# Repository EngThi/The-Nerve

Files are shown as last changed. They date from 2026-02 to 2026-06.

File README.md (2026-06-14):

# The Nerve Automation Motherboard

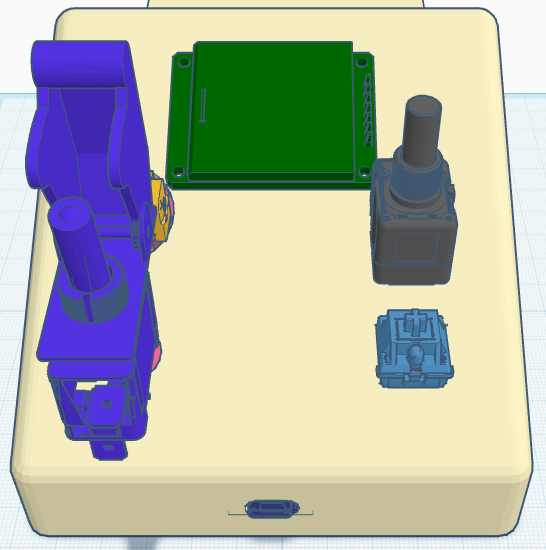
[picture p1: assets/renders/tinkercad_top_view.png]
The Nerve Hero Render


> [!IMPORTANT]
> Reviewer, this project is a custom board placed in Tier 3. To stay within the $100 budget including international shipping fees and taxes, Version A (Round TFT) is the primary build configuration. All components are hand-soldered.



The Nerve is a modular controller for automation workflows and video pipelines. It uses an ESP32-S3 for native Wi-Fi, Bluetooth, and USB HID support.

[Specs](#hardware) | [Logs](JOURNAL.md) | [Budget](BLUEPRINT_BUDGET.md) | [Production](hardware/production/)

---

## Hardware Design

The PCB was designed in EasyEDA and the enclosure in OnShape.

### Enclosure Design
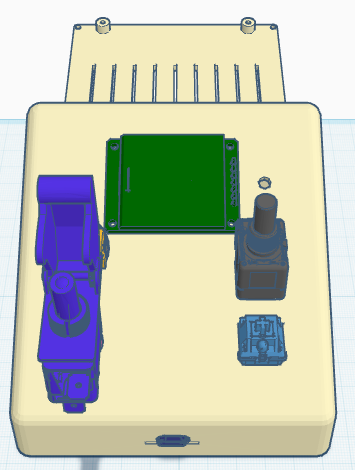
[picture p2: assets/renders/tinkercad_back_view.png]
Enclosure Back View

- [OnShape Public Link](https://cad.onshape.com/documents/f5fe8f1a3f0d54ab7cd3f1d7/w/a16133ebbda184e0e50a9073/e/bf72140826f3054b8f947155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)
- [Tinkercad 3D Model](https://www.tinkercad.com/things/edG28wTrG8o-enclousure-the-nerve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)

### PCB Layout
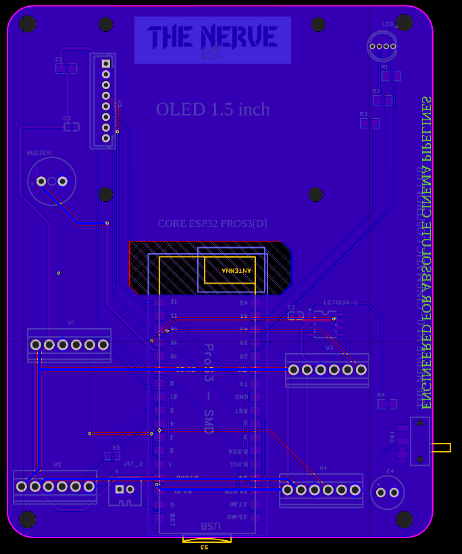
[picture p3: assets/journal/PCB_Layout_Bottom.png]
PCB Bottom Layout

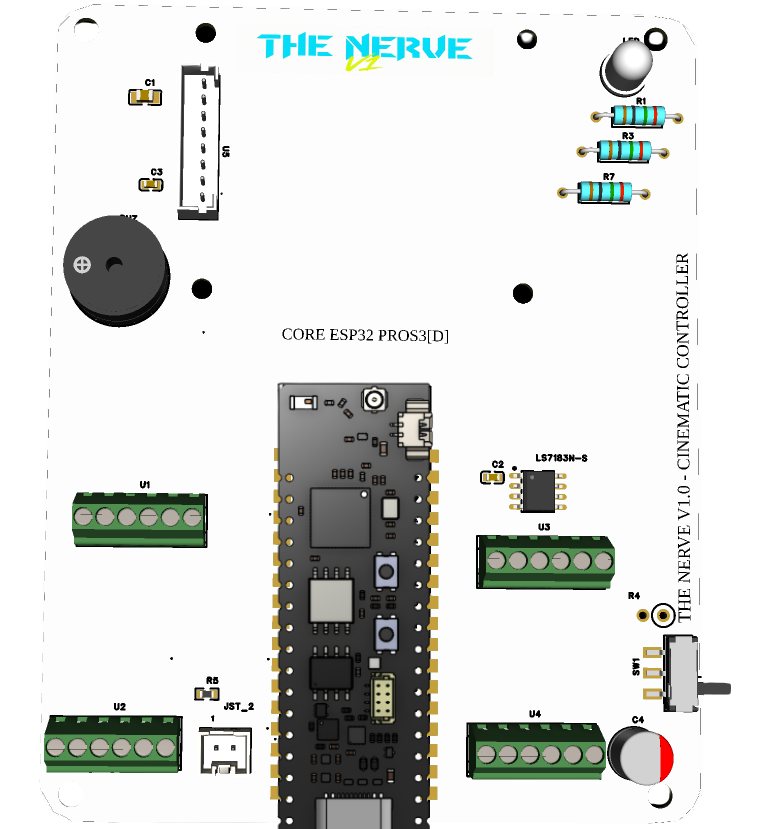
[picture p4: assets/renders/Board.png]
PCB Render


- [Project Link in the Editor](https://pro.easyeda.com/editor#id=794fe6f5b1b64e09b8597b022e057335)

### BOM (Version A - Round TFT)
| Part | Description | Price | Link |
| :--- | :--- | :--- | :--- |
| **ESP32-S3-DevKit-LiPo** | Native USB HID and built-in LiPo charging. | $8.70 | [Olimex](https://www.olimex.com/Products/IoT/ESP32-S3/ESP32-S3-DevKit-Lipo.html) |
| **Custom PCB (5pcs)** | 2-layer PCB fabrication. | $4.00 | JLCPCB |
| **Toggle Switch Missile Cover** | Safety arming switch | $3.73 | [AliExpress](https://aliexpress.com/item/1005006733525021.html) |
| **Outemu MX Switches (5pcs)** | Mechanical switches | $2.12 | [Shopee](https://shopee.com.br/Switch-Outemu-Para-Teclado-Mec%C3%A2nico-Diversas-Cores-Blue-Red-Brown-Green-Purple-Frete-Gr%C3%A1tis-i.374734112.23418702594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) |
| **K-Silver JH16 Hall Joystick (2x)**| Hall Effect analog stick | $8.12 | [AliExpress](https://aliexpress.com/item/1005008728261473.html) |
| **EC11 Rotary Encoder (10pcs)** | Rotary input | $2.58 | [AliExpress](https://aliexpress.com/item/2001241262.html) |
| **JST-PH 2.0mm 2P Connector** | Required for battery connection | $1.31 | [AliExpress](https://aliexpress.com/item/33024777806.html) |
| **Round TFT GC9A01 Display** | 1.28 inch SPI display. | $1.38 | [AliExpress](https://aliexpress.com/item/1005008284550510.html) |
| **LiPo 1800mAh 3.7V Battery** | Standalone power source. | $5.05 | [Shopee](https://shopee.com.br/Bateria-Lipo-1800mah-3.7v-3-Fios-10x34x50-3-7v-Lithium-1s1p-i.389386479.55550251664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) |
| **SMD Components Batch** | LCSC Caps, Resistors, ICs (LS7183N-S) | $14.38 | LCSC |

*(Full details and shipping/taxes breakdown in the [Hardware Budget](BLUEPRINT_BUDGET.md) and [BOM CSV](the_nerve_bom.csv))*

---

## How to Use

So, The Nerve works like a node or a kind of independent trigger that communicates with your computer (or server, those types of HID interfaces, etc) to run automated tasks. I like the part of triggering n8n/general webhooks or running FFmpeg video processing scripts, controlling something on your PC

### Hardware Setup and Firmware Flashing
1. **Wire the Panel:** Connect the Joystick to the `ADC1` pins (Pins 1 and 2), the Rotary Encoder to the Quadrature Decoder pins (Pins 15 and 16) and the Cherry MX Switch and the Missile Toggle to their respective JST ports, according to the [Wiring Diagram](assets/diagrams/EXTERNAL_WIRING_GUIDE.png) that is right below. This way you can swap ports but they have to be compatible with the type of signal and mechanics of that device you are going to use.

2. **Flash the Firmware:** Connect the ESP32 via USB-C. Install MicroPython on the board and upload the `firmware/main.py` file (or whatever you develop for your own type of use). You can improve or change this entirely, since I developed it to be multi-use and very customizable. Use different types of components, parts, etc

3. **Turn on:** You can turn it on through the USB-C cable or totally independently using the 1800mAh LiPo battery (the ProS3 and even the new one from Olimex has built-in charging) . Upon turning on, it plays a startup tone and the RGB LED turns blue.

### Operation
- **Safety Switch (Safety Lock):** Before running any command, you must lift the switch cover and turn it on. The system will be armed and an LED indicator will light up.
- **Intensity Selector (Rotary Encoder):** Turn the encoder to adjust the "Intensity Level" (0 to 100). The RGB LED changes from blue to red to visually represent the intensity level you are setting for your automation task.

- **Timeline Navigation (Joystick):** Move the joystick to adjust the X/Y parameters (useful for navigating the timeline or adjusting the visual positioning in your scripts).
- **Execute (Cherry MX Switch):** Press the mechanical switch to fire the command. If the missile switch is *armed*, it will flash white, play an execution tone and send a JSON payload via serial (or via Wi-Fi through webhooks) containing all the dial and joystick parameters. If it's *disarmed*, it will flash red and play an error warning tone.

 Open n8n and import the workflows found in the `automation/n8n/flows/` directory.

The `trigger_executor.json` file brings a script that waits for a webhook.

A local Python script on your PC (or directly on the ESP32 via Wi-Fi) listens to the JSON serial output from The Nerve and forwards it to your n8n webhook (or wherever it is, kinda), which then parses the "Hype Level" and Joystick parameters to run the logic of the `video_pipeline.json` file.

I think that's pretty much it :P

---

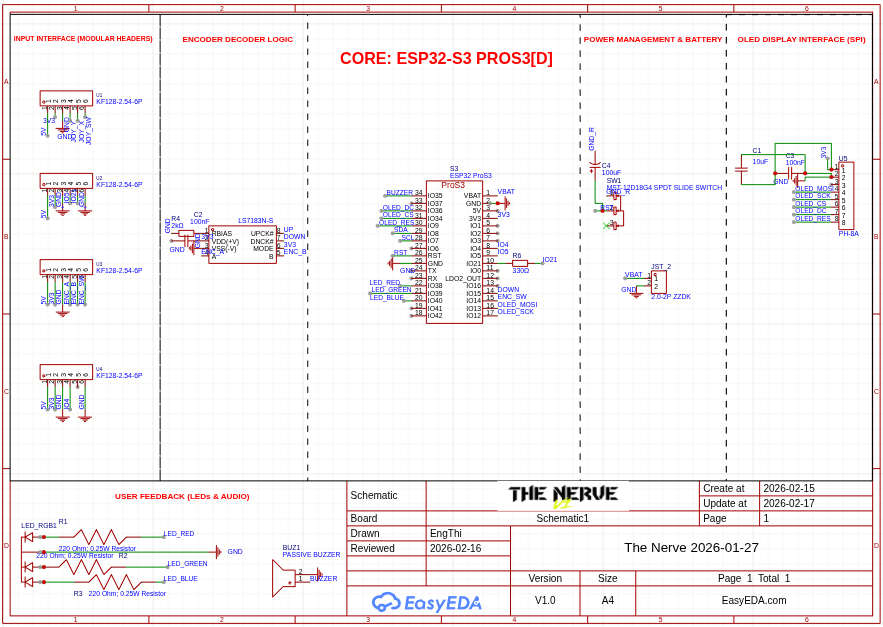
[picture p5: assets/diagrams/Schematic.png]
Schematic Diagram


---

## Build and Budget

The total delivered cost for Version A is **$99.77**.

Detailed evidence can be found in the [Hardware Budget](BLUEPRINT_BUDGET.md).

### Evidence Gallery
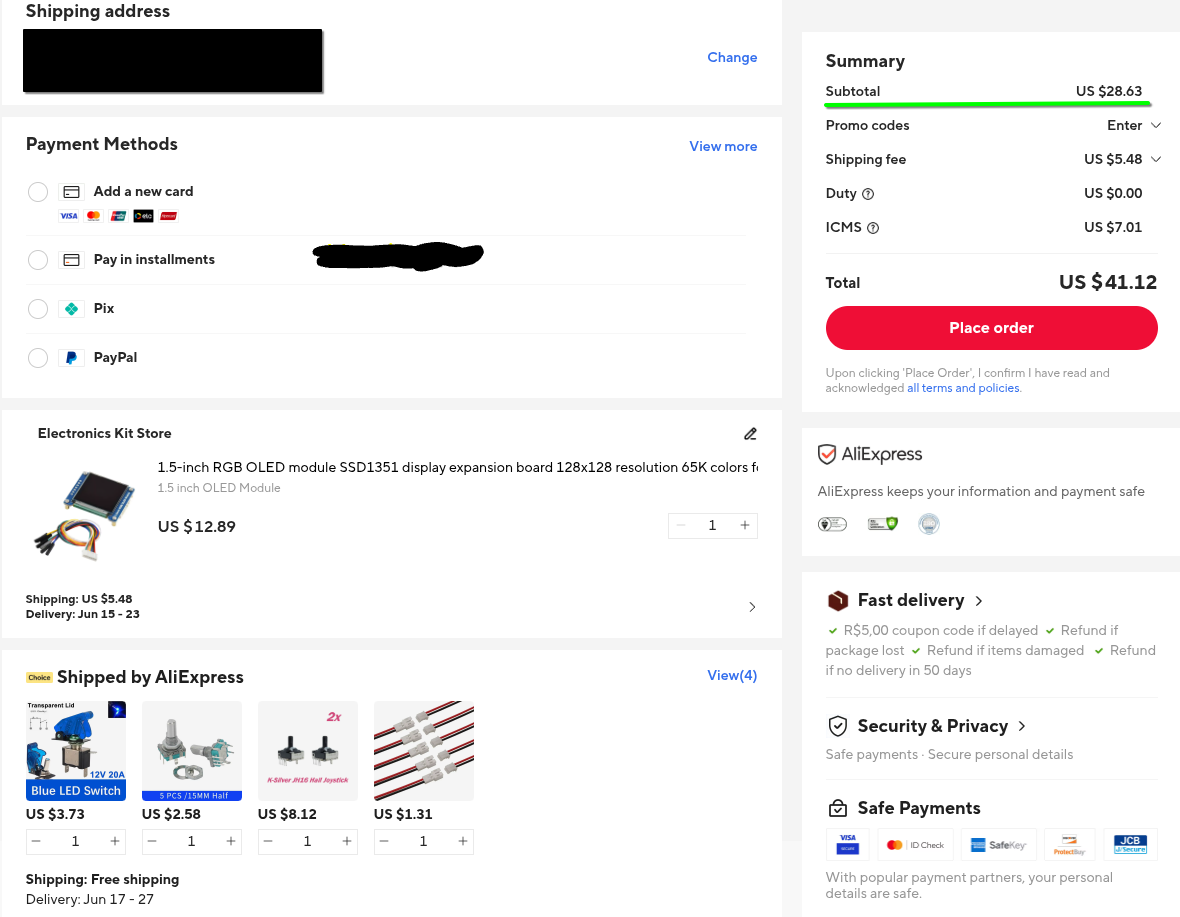
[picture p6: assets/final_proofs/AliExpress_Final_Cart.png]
AliExpress Proof

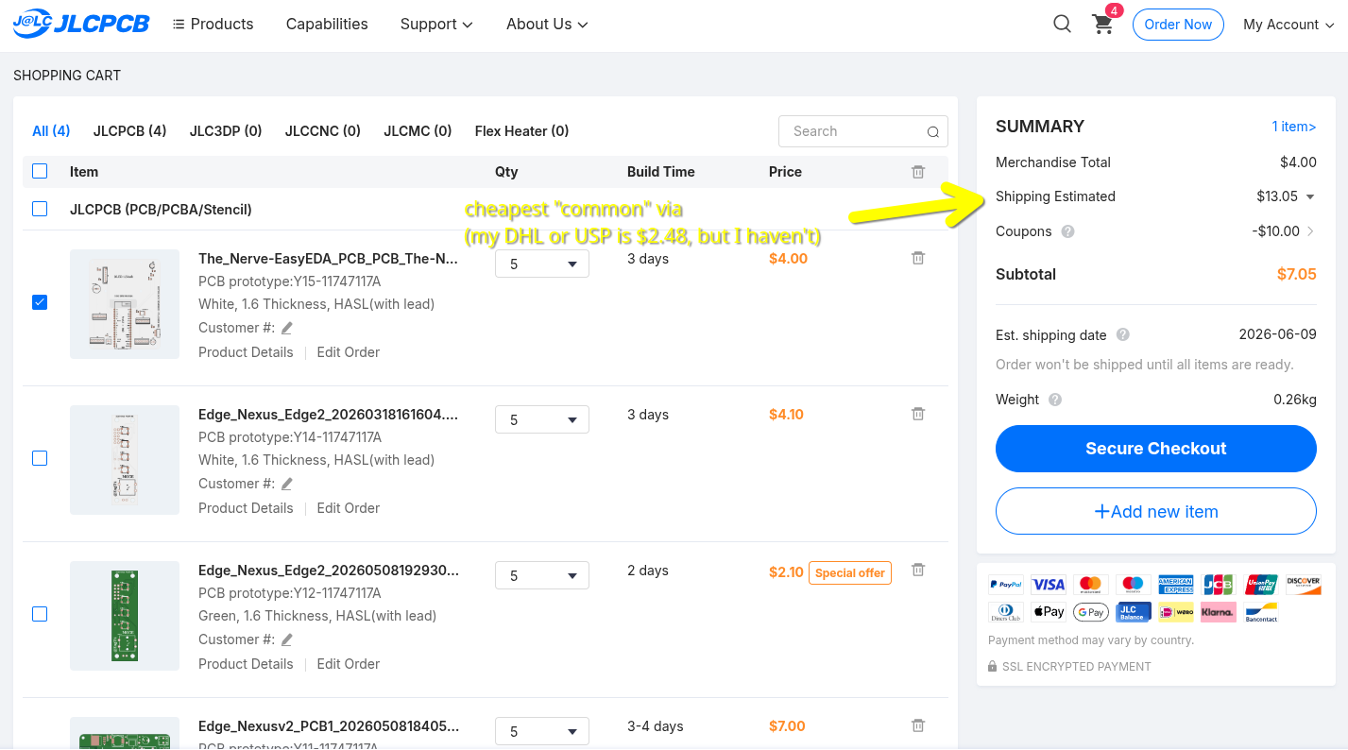
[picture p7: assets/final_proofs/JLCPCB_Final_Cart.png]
JLCPCB Proof

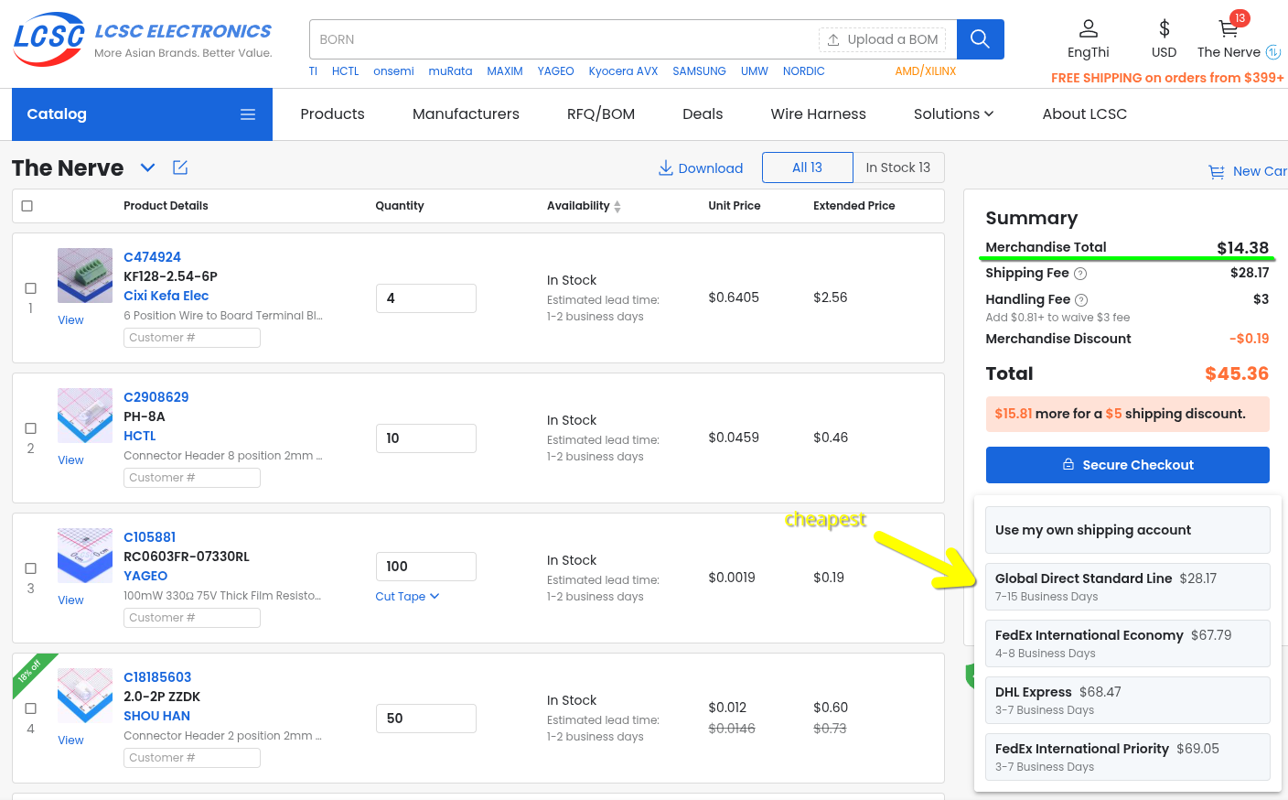
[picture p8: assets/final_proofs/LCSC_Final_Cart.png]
LCSC Proof

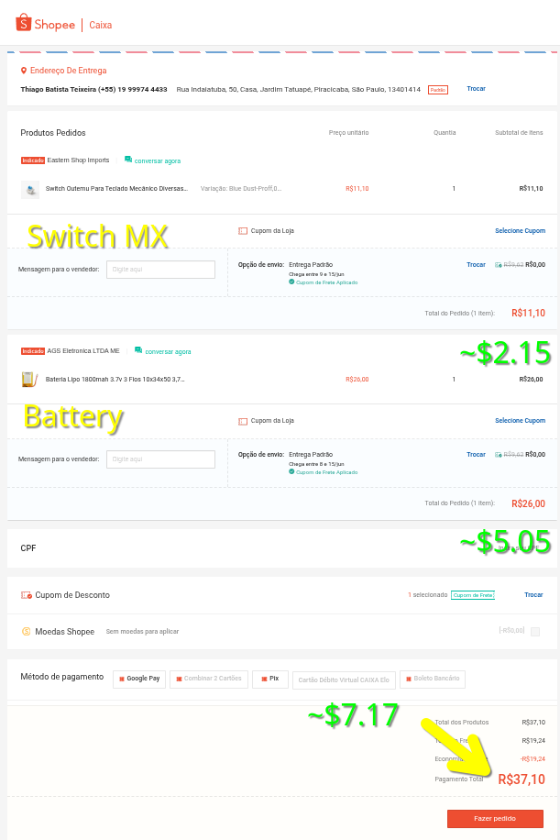
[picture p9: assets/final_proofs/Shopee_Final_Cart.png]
Shopee Proof


---

_Designed by ChefThi for Hack Club Blueprint._

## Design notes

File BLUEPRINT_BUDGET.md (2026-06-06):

# The Nerve Hardware Budget

This document outlines the hardware costs for The Nerve. To make it easier to understand, the budget is split into **Component Base Prices** (the actual cost of the parts) and **Shipping & Taxes** (the fees to get them to Brazil).

Version A is the official submission for the Hack Club Tier 3 grant ($100 limit).

### 1. Component Base Prices (Version A - Round TFT)

| Part | Supplier | Price (USD) |
| :--- | :--- | :--- |
| ESP32-S3-DevKit-LiPo | Olimex | $8.70 |
| Custom PCB (5pcs) | JLCPCB | $4.00 |
| Toggle Switch Missile Cover | AliExpress | $3.73 |
| Outemu MX Switches (10pcs) | Shopee BR | $2.12 |
| K-Silver JH16 Hall Joystick (2x) | AliExpress | $8.12 |
| EC11 Rotary Encoder (10pcs) | AliExpress | $2.58 |
| JST-PH 2.0mm 2P Connector | AliExpress | $1.31 |
| Round TFT GC9A01 Display | AliExpress | $1.38 |
| LiPo 1800mAh 3.7V Battery | Shopee BR | $5.05 |
| SMD Components Batch | LCSC | $14.38 |
| **Subtotal Components** | | **$51.37** |

---

### 2. Shipping & Regional Taxes

These are the necessary shipping costs and taxes to deliver the components.

| Supplier / Fee Type | Cost (USD) |
| :--- | :--- |
| JLCPCB Shipping | $13.05 |
| LCSC Shipping (Global Direct) | $31.17 |
| AliExpress Taxes (ICMS) | $4.18 |
| Olimex / Shopee Shipping | $0.00 |
| **Subtotal Shipping & Taxes** | **$48.40** |

---

### 3. Final Total

| Version A | $51.37 (Parts) + $48.40 (Shipping/Taxes) | **$99.77** |
| :--- | :--- | :--- |

*(Note: Version B with a standard OLED SSD1351 brings the total to ~$119.40, and Version C with a premium OLED brings it to ~$121.20. Both exceed the Tier 3 limit and are for reference only).*

### Proof of Costs (Final Carts)
- [AliExpress Final Cart](assets/final_proofs/AliExpress_Final_Cart.png)
- [JLCPCB Final Cart](assets/final_proofs/JLCPCB_Final_Cart.png)
- [LCSC Final Cart](assets/final_proofs/LCSC_Final_Cart.png)
- [Shopee Final Cart](assets/final_proofs/Shopee_Final_Cart.png)

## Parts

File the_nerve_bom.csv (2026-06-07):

No. | Quantity | Comment | Designator | Footprint | Value | Manufacturer Part | Manufacturer | Supplier Part | Supplier | Link | 3D Model Title | JLCPCB Price | LCSC Price | Category | Device | Notes
1 | 1 | 2.7kHz | BUZZER1 | BUZ-TH_BD9.0-P4.00-D0.6-FD | 2.7kHz | QMB-09B-03 | 华能 | C96256 | LCSC | https://www.lcsc.com/product-detail/C96256.html | BUZ-TH_D9.0-H5.5-P4.0 | 176 |  | Audio Products:Buzzers | QMB-09B-03
2 | 1 | 10uF | C1 | C0805 | 10uF | CL10A106KP8NNNC | SAMSUNG | C19702 | LCSC | https://www.lcsc.com/product-detail/C19702.html | C0805_L2.0-W1.3-H1.3 | 23 |  | Capacitors:MLCC | CL10A106KP8NNNC
3 | 2 | 100nF | C2 C3 | C0603 | 100nF | CL05B104KO5NNNC | SAMSUNG | C1525 | LCSC | https://www.lcsc.com/product-detail/C1525.html | C0603_L1.6-W0.8-H0.8 | 3 |  | Capacitors:MLCC | CL05B104KO5NNNC
4 | 1 | 100uF | C4 | CAP-TH_BD6.3-P2.5-D0.6-FD-RYHG35V100UF |  | RYHG35V100UF6*8 | HONOR | C48970442 | LCSC | https://www.lcsc.com/product-detail/C48970442.html | CAP-TH_BD6.3-P2.5-D0.6-FD-RYHG35V100UF | 196 |  |  | 100uF
5 | 1 | 2.0-2P ZZDK | JST_2 | HDR-TH_2P-P2.00-V-F-2 |  | 2.0-2P ZZDK | SHOU HAN | C18185603 | LCSC | https://www.lcsc.com/product-detail/C18185603.html | HDR-TH_2P-P2.00-V-F-2 |  |  |  | 2.0-2P ZZDK
6 | 1 | RGB LED | LED_RGB | LED-TH_4P-BD5.8-P1.30 |  | TJ-L5FYTXHMCSLCRGB-A5 | TOGIALED | C330759 | LCSC | https://www.lcsc.com/product-detail/C330759.html | LED-TH_4P-BD5.8-P1.30-RGB | 217 |  | Optoelectronics:RGB LEDs | TJ-L5FYTXHMCSLCRGB-A5
7 | 1 | LS7183N-S | LS7183N-S | SOIC-8_L4.9-W3.9-P1.27-LS6.0-TL |  | LS7183N-S | LSI/CSI | C3234982 | LCSC | https://www.lcsc.com/product-detail/C3234982.html | SOIC-8_L4.9-W3.9-H1.7-LS6.0-P1.27 | 1.0406 |  |  | LS7183N-S | Hardware quadrature decoder
8 | 3 | 220Ω | R1 R2 R3 | R0805 | 220Ω | RTT052200FTP | RALEC | C104105 | LCSC | https://www.lcsc.com/product-detail/C104105.html | R0805_L2.0-W1.3-H0.6 | 4 |  | Resistors:Surface Mount | RTT052200FTP
9 | 1 | 2kΩ | R4 | R0805 | 2kΩ | RS-05K2001FT | FH | C132365 | LCSC | https://www.lcsc.com/product-detail/C132365.html | R0805_L2.0-W1.3-H0.6 | 5 |  | Resistors:Surface Mount | RS-05K2001FT
10 | 1 | 330Ω | R5 | R0603 | 330Ω | RC0603FR-07330RL | YAGEO | C105881 | LCSC | https://www.lcsc.com/product-detail/C105881.html | R0603 | 3 |  |  | R0603
11 | 1 | ESP32 S3 | S3 |  |  | S3 | Olimex | ESP32-S3-DevKit-Lipo | Olimex | https://www.olimex.com/Products/IoT/ESP32-S3/ESP32-S3-DevKit-Lipo.html |  |  | (in this case is'nt LCSC) 8.70 | MCU | ESP32 S3 | Built-in LiPo charger
12 | 1 | Power Switch | SW1 | SW-SMD_MST-12D18G4-SPDT-SLIDE-SWITCH |  | MST-12D18G4 | SHOU HAN | C49023767 | LCSC | https://www.lcsc.com/product-detail/C49023767.html | SW-SMD_MST-12D18G4-SPDT-SLIDE-SWITCH | 123 |  |  | MST-12D18G4 SPDT SLIDE SWITCH
13 | 4 | 6-Pin Terminal | U1 U2 U3 U4 | CONN-TH_6P-P2.54_KF128-2.54-6P |  | KF128-2.54-6P | KEFA | C474924 | LCSC | https://www.lcsc.com/product-detail/C474924.html | CONN-TH_6P-P2.54_KF128-2.54-6P | 955 |  |  | KF128-2.54-6P | Pluggable System Terminal
14 | 1 | 8-Pin Conn | U5 | CONN-TH_8P-P2.00_HCTL_PH-8A_C2908629 |  | PH-8A | HCTL | C2908629 | LCSC | https://www.lcsc.com/product-detail/C2908629.html | CONN-TH_8P-P2.00_HCTL_PH-8A_C2908629 | 68 |  |  | PH-8A
15 | 1 | Custom PCB | PCB | Custom | 2-layer | The Nerve V1.0 | JLCPCB | N/A | JLCPCB | https://jlcpcb.com/ |  | 4.00 |  | Fabrication | PCB | Official project boards (5pcs)
16 | 1 | Toggle Switch | PANIC_SW | JST Port |  | Missile LED Switch | Generic | N/A | AliExpress | https://aliexpress.com/item/1005006733525021.html |  | 3.73 |  | User Interface | Safety Arm Switch | Panic Button Trigger
17 | 1 | Mechanical SW | MX_SW | JST Port |  | Outemu MX Switches | Outemu | N/A | Shopee | https://shopee.com.br/Switch-Outemu-Para-Teclado-Mec%C3%A2nico-Diversas-Cores-Blue-Red-Brown-Green-Purple-Frete-Gr%C3%A1tis-i.374734112.23418702594 | 5.0pcs | 2.12 |  | User Interface | Cherry MX Port | Execute trigger
18 | 2 | Hall Joystick | JOY_1 2 | Terminal |  | JH16 Hall Stick | K-Silver | N/A | AliExpress | https://aliexpress.com/item/1005008728261473.html |  | 8.12 |  | User Interface | JH16 Hall Sensor | Hall Effect analog control
19 | 1 | Rotary Encoder | ENC_1 | Terminal |  | EC11 Encoder | Generic | N/A | AliExpress | https://aliexpress.com/item/2001241262.html |  | 2.58 |  | User Interface | EC11 Rotary | Hype Dial control
20 | 1 | JST Connector | BATT_CONN | PH 2.0mm |  | JST-PH 2P M+F | Generic | N/A | AliExpress | https://aliexpress.com/item/33024777806.html |  | 1.31 |  | Power | JST-PH 2.0 | Battery plug
21 | 1 | Round Display | DISP_A | SPI |  | GC9A01 1.28-inch | Generic | N/A | AliExpress | https://aliexpress.com/item/1005008284550510.html |  | 1.38 |  | Display | GC9A01 TFT | Primary Version A Display
22 | 1 | LiPo Battery | BATTERY | JST-PH |  | 1800mAh 3.7V | Generic | N/A | Shopee | https://shopee.com.br/Bateria-Lipo-1800mah-3.7v-3-Fios-10x34x50-3-7v-Lithium-1s1p-i.389386479.55550251664 |  | 05.05 |  | Power | 1800mAh 1S | Main standalone power

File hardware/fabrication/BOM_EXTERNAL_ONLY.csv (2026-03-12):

ID | Name | Designator | Quantity | Manufacturer | Supplier | Supplier Part | Price | Link | Notes
14 | LiPo Battery 3000mAh | BATT_A | 1 | Hiteuoms | Amazon | B0DP2JKFJG | 9.99 | https://www.amazon.com/dp/B0DP2JKFJG | Power Source (JST 1.25mm Type)
15 | LiPo Battery 2200mAh | BATT_B | 1 | OXWINOU | Amazon | B0CTQ6VBB6 | 9.98 | https://www.amazon.com/dp/B0CTQ6VBB6 | Power Source (JST 2.0mm Type)
16 | Cherry MX Blue Switch | SW_MECH | 1 | Cherry | MechKeyboards | MX2A-Blue | 0.40 | https://mechanicalkeyboards.com/products/cherry-mx2a-blue-60g-clicky?variant=48020492124460 | Main Trigger (Clicky)
17 | Illuminated Toggle Switch | SW_MISSILE | 1 | Adafruit | Adafruit | 3306 | 3.95 | https://www.adafruit.com/product/3306 | Safety Arming Switch
18 | Hall Effect Joystick | JOY1 | 1 | VGBUS | Amazon BR | B0CXDTGXZP | 16.46 | https://www.amazon.com.br/dp/B0CXDTGXZP | Analog Control (Drift Free)
19 | ESP32-S3 ProS3 | U_MCU | 1 | Unexpected Maker | Adafruit | 6398 | 26.50 | https://www.adafruit.com/product/6398 | Main Controller
20 | 1.5inch RGB OLED | DISP1 | 1 | Waveshare | Waveshare | 1.5inch RGB OLED | 16.99 | https://www.waveshare.com/1.5inch-rgb-oled-module.htm | Visual Interface
21 | Mechanical Encoder (Alps) | ENC_MECH | 1 | Alps Alpine | Mouser | 688-EC11E15244B2 | 4.85 | https://br.mouser.com/ProductDetail/Alps-Alpine/EC11E15244B2?qs=m0BA540hBPfDpUEkDmFV5A%3D%3D | 15PPR, 3.3V Logic Compatible
22 | Optical Encoder (Bourns) | ENC_OPT | 1 | Bourns | Mouser | 652-ENA1J-B28-L064L | 46.03 | https://br.mouser.com/ProductDetail/Bourns/ENA1J-B28-L00064L?qs=CrTVAl0CcnKhSZ6oFfhmHw%3D%3D | 64PPR, High-Precision, 5V Supply
23 | Silicone Wire Kit 24AWG | WIRE_KIT | 1 | BNTECHGO | Amazon | B09X4HVFJX | 9.98 | https://www.amazon.com/dp/B09X4HVFJX | 10 Color Each 5 ft Flexible 24 AWG Stranded Tinned Copper Wire

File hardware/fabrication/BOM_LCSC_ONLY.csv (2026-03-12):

ID | Name | Designator | Quantity | Manufacturer | Supplier | Supplier Part | Price | Link | Notes
1 | Capacitor 10uF 0805 | C1 | 20 | Samsung Electro-Mechanics | LCSC | C1713 | 0.0116 | https://www.lcsc.com/product-detail/C1713.html | Decoupling Cap (Cut Tape Min 20)
2 | Resistor 220Ω | R1/R3/R7 | 3 | Tyohm | LCSC | C410657 | 0.0097 | https://jlcpcb.com/partdetail/TyoHM-RN_1_4W_220R_F_T_BA1/C410657 | Current Limiting
3 | Resistor 330Ω | R5 | 1 | YAGEO | LCSC | C105881 | 0.0014 | https://lcsc.com/product-detail/Chip-Resistor-Surface-Mount_YAGEO-RC0603FR-07330RL_C105881.html | LED Resistor
4 | Resistor 2kΩ | R4 | 1 | UNI-ROYAL | LCSC | C58680 | 0.0084 | https://www.lcsc.com/product-detail/C58680.html | Pull-up (OUT OF STOCK)
5 | Screw Terminal 6-Pin 2.54mm | U1-U4 | 4 | KEFA | LCSC | C474924 | 0.6375 | https://lcsc.com/product-detail/Pluggable-System-Terminal-Block_KEFA-KF128-2-54-6P_C474924.html | Quantities adjusted for LCSC MOQ (Blueprint Verified)
6 | Conn JST PH 2.0mm 2-Pin | JST_2 | 50 | JST | LCSC | C18185603 | 0.012 | https://www.lcsc.com/product-detail/C131337.html | Quantities adjusted for LCSC MOQ (Blueprint Verified)
7 | Conn PH 2.0mm 8-Pin | U5 | 10 | Megastar | LCSC | C2908629 | 0.0454 | https://www.lcsc.com/product-detail/C7429584.html | Quantities adjusted for LCSC MOQ (Blueprint Verified)
8 | Passive Buzzer (MOQ 5) | BUZ | 5 | Generic | LCSC | C96256 | 0.1161 | https://www.lcsc.com/product-detail/C96256.html | Quantities adjusted for LCSC MOQ (Blueprint Verified)
9 | Capacitor 100nF 0603 | C2/C3 | 2 | AIDE | LCSC | C49326605 | 0.0017 | https://lcsc.com/product-detail/Multilayer-Ceramic-Capacitors-MLCC-SMD-SMT_AIDE-0603X7R104K100NT_C49326605.html | Filter Cap (OUT OF STOCK)
10 | Capacitor 100uF Radial (MOQ 5) | C4 | 5 | HONOR | LCSC | C48970442 | 0.1275 | https://lcsc.com/product-detail/Aluminum-Electrolytic-Capacitors-Leaded_HONOR-RYHG35V100UF6-8_C48970442.html | Quantities adjusted for LCSC MOQ (Blueprint Verified)
11 | LED RGB 5mm (Pack of 10) | LED_RGB | 10 | XINGLIGHT | LCSC | C7371892 | 0.0566 | https://www.lcsc.com/product-detail/C7371892.html | Quantities adjusted for LCSC MOQ (Blueprint Verified)
12 | Decoder IC LS7183N-S | U_DEC | 1 | LSI/CSI | LCSC | C3234982 | 7.0064 | https://lcsc.com/product-detail/Encoders_LSI-CSI-LS7183N-S_C3234982.html | Quadrature Decoder
13 | SPDT Slide Switch | SW1 | 1 | SHOU HAN | LCSC | C49023767 | 0.0780 | https://lcsc.com/product-detail/Slide-Switches_SHOU-HAN-MST-12D18G4-SPDT-SLIDE-SWITCH_C49023767.html | Power Switch
99 | LCSC Shipping Fee | SHIP | 1 | LCSC | LCSC | N/A | 9.12 | N/A | Global Direct Standard Line
100 | LCSC Handling Fee | FEE | 1 | LCSC | LCSC | N/A | 3.00 | N/A | LCSC Service Charge
101 | LCSC Discount | DISC | 1 | LCSC | LCSC | N/A | -0.16 | N/A | Merchandise Discount

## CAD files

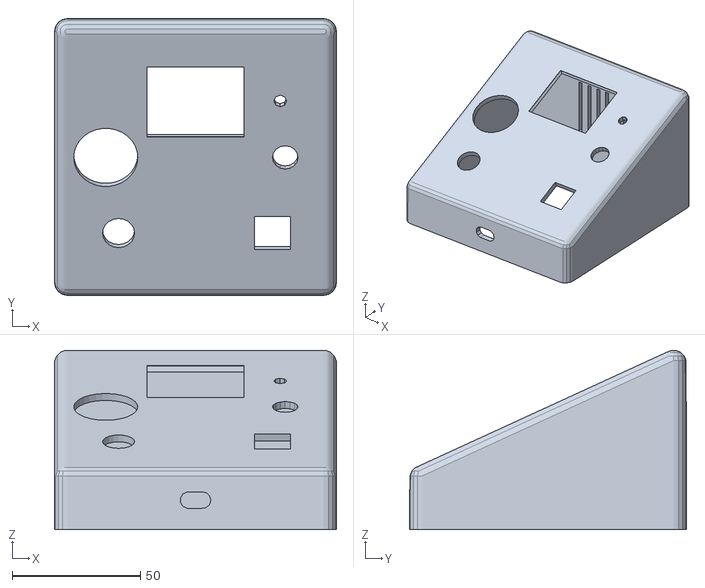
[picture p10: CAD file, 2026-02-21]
hardware/3d_models/the_nerve_case_main.stl
110.0 x 108.0 x 69.9

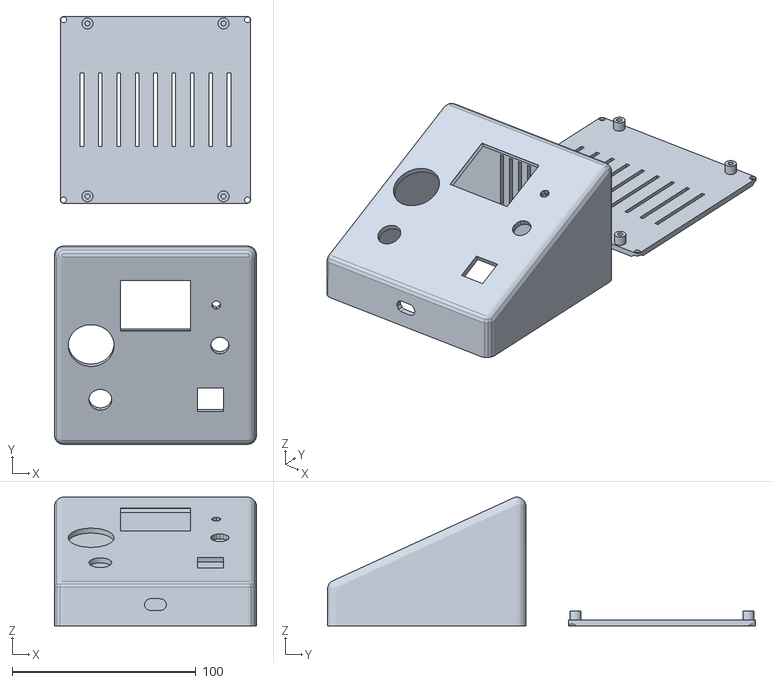
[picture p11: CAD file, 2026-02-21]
hardware/3d_models/the_nerve_case_full_assembly.stl
110.0 x 232.8 x 69.9

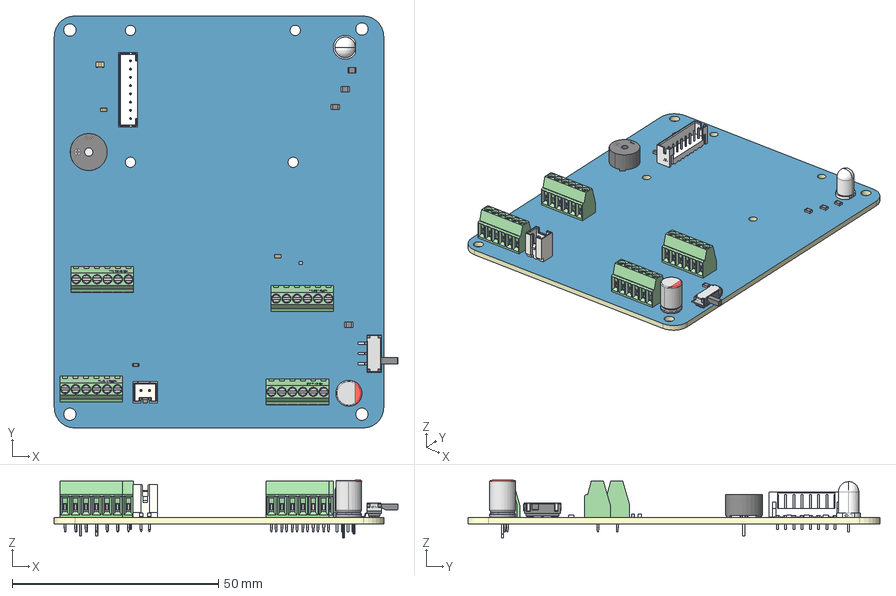
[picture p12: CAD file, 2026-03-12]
hardware/3d_models/the_nerve_pcb.step
83.4 x 100.0 x 14.0 mm
Board~MBTE
TopCopper~MBTE
BottomCopper~MBTE
TopFpcStiffener~MBTE
BottomFpcStiffener~MBTE
C0805~C0805_L2.0-W1.3-H1.3~MBTE
C0603~C0603_L1.6-W0.8-H0.8~MBTE x 2
CONN-TH_8P-P2.00_HCTL_PH-8A_C2908629~CONN-TH_8P-P2.00_HCTL_PH-8A_ C2908629~MBTE
R0603~R0603~MBTE
HDR-TH_2P-P2.00-V-F-2~HDR-TH_2P-P2.00-V-F-2~MBTE
R0805~R0805_L2.0-W1.3-H0.6~MBTE x 4
LED-TH_4P-BD5.8-P1.30~LED-TH_4P-BD5.8-P1.30-RGB~MBTE
BUZ-TH_BD9.0-P4.00-D0.6-FD~BUZ-TH_D9.0-H5.5-P4.0~MBTE
SOIC-8_L4.9-W3.9-P1.27-LS6.0-TL~SOIC-8_L4.9-W3.9-H1.7-LS6.0-P1.27~MBTE
CONN-TH_6P-P2.54_KF128-2.54-6P~CONN-TH_6P-P2.54_KF128-2.54-6P~MBTE x 4
CAP-TH_BD6.3-P2.5-D0.6-FD-RYHG35V100UF~CAP-TH_ BD6.3-P2.5-D0.6-FD-RYHG35V100UF~MBTE
SW-SMD_MST-12D18G4-SPDT-SLIDE-SWITCH~SW-SMD_ MST-12D18G4-SPDT-SLIDE-SWITCH~MBTE

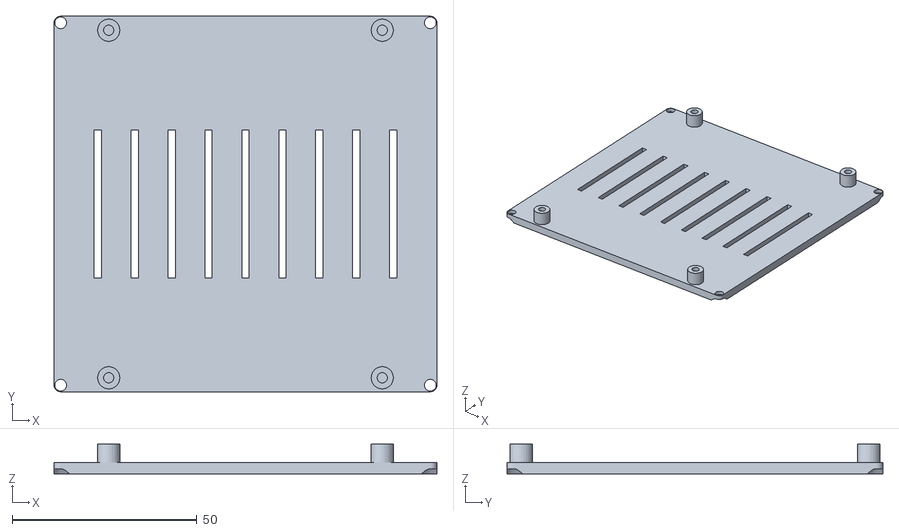
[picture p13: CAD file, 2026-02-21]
hardware/3d_models/the_nerve_case_bottom.stl
103.6 x 101.6 x 8.00

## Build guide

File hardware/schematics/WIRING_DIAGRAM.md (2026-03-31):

# The Nerve – Wiring Diagram

Complete wiring reference for all components listed in `BOM.csv`. All signal levels are **3.3V** unless noted.

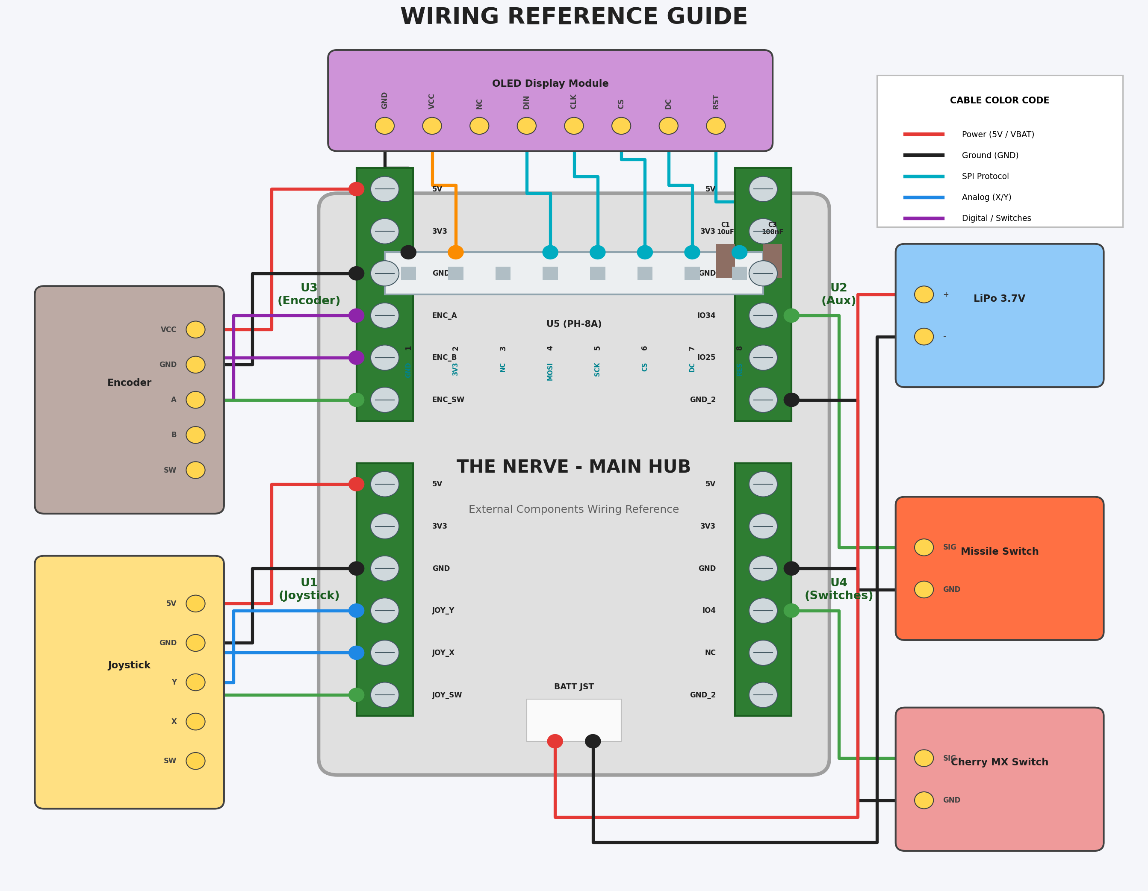
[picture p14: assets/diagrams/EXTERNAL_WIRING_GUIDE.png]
The Nerve External Wiring Guide


---

## MCU: ESP32-S3 ProS3 (U_MCU)

> Unexpected Maker ProS3 – [Adafruit #6398](https://www.adafruit.com/product/6398)

All peripherals connect to the ESP32-S3 ProS3 via its labeled GPIO header.

---

## 1. Hall Effect Joystick (JOY1 – VGBUS B0CXDTGXZP)

| Joystick Pin | ESP32-S3 Pin | Notes |
|---|---|---|
| VCC | 3.3V | Regulated from onboard LDO |
| GND | GND | |
| X-AXIS (Analog) | IO1 | ADC Channel |
| Y-AXIS (Analog) | IO2 | ADC Channel |
| BTN (Click) | IO3 | Internal Pull-UP; active LOW |

> **Pull-up:** IO3 uses the ESP32-S3 internal pull-up (enabled in firmware).

---

## 2. Quadrature Encoder (ENC_MECH or ENC_OPT) + LS7183N-S Decoder (U_DEC)

The raw encoder output feeds through the **LS7183N-S** (ID 12 in BOM) quadrature decoder IC before reaching the ESP32-S3. This offloads pulse counting from the firmware.

### Encoder → LS7183N-S

| Encoder Pin | LS7183N-S Pin | Notes |
|---|---|---|
| A (Phase A) | QA (Pin 3) | |
| B (Phase B) | QB (Pin 4) | |
| VCC | VDD (Pin 8) | 3.3V (Alps) or 5V (Bourns—use level shifter) |
| GND | GND (Pin 1) | |

> ⚠️ **Optical Encoder (Bourns ENA1J-B28):** Requires 5V supply (Pin 8). Use a 3.3V↜5V level shifter on A/B lines going into LS7183N-S if using 3.3V logic side.

### LS7183N-S → ESP32-S3

| LS7183N-S Pin | ESP32-S3 Pin | Notes |
|---|---|---|
| QU (CW pulse, Pin 5) | IO15 | Pull-UP; CW tick |
| QD (CCW pulse, Pin 6) | IO16 | Pull-UP; CCW tick |

### Encoder Push-Button

| Encoder BTN Pin | ESP32-S3 Pin | Notes |
|---|---|---|
| BTN | IO14 | Internal Pull-UP; active LOW |
| GND | GND | |

---

## 3. OLED Display (DISP1 – Waveshare 1.5" RGB SPI 128×128)

| OLED Pin | ESP32-S3 Pin | Notes |
|---|---|---|
| VCC | 3.3V | |
| GND | GND | |
| DIN (MOSI) | IO35 | SPI Data |
| CLK | IO36 | SPI Clock |
| CS | IO37 | Chip Select (active LOW) |
| DC | IO38 | Data/Command select |
| RST | IO39 | Reset (active LOW) |

---

## 4. RGB LED (LED_RGB – XL-A504RGBW, Common Cathode)

Each channel uses a current-limiting resistor per BOM.

| LED Pin | Resistor | ESP32-S3 Pin | Notes |
|---|---|---|---|
| R (Anode) | R1 – 220Ω | IO7 | Active HIGH |
| G (Anode) | R3 – 220Ω | IO8 | Active HIGH |
| B (Anode) | R7 – 220Ω | IO9 | Active HIGH |
| Cathode | — | GND | Common cathode |

---

## 5. Passive Buzzer (BUZ – QMB-09B-03)

| Buzzer Pin | Connection | Notes |
|---|---|---|
| + | IO10 (via R5 – 330Ω) | Active HIGH |
| − | GND | |

> **R5 (330Ω)** limits current and protects the GPIO output.

---

## 6. Cherry MX Blue Switch (SW_MECH)

| Switch Pin | ESP32-S3 Pin | Notes |
|---|---|---|
| Pin 1 | IO4 | Internal Pull-UP; active LOW |
| Pin 2 | GND | |

---

## 7. Illuminated Toggle Switch – Missile Switch (SW_MISSILE – Adafruit 3306)

| Toggle Pin | Connection | Notes |
|---|---|---|
| COM | GND | |
| NO (Normally Open) | IO5 | Internal Pull-UP; active LOW |
| LED + | 3.3V (via R4 – 2kΩ) | Built-in LED |
| LED − | GND | R4 limits LED current |

---

## 8. SPDT Power Slide Switch (SW1)

The slide switch interrupts the **battery positive rail** directly – not connected to any GPIO.

| Switch Pin | Connection |
|---|---|
| COM | LiPo Battery (+) via JST 2-Pin |
| NO | VIN / 5V rail of ESP32-S3 ProS3 |
| NC | Not connected |

---

## 9. LiPo Battery

| Battery Pin | Connection | Notes |
|---|---|---|
| + | SW1 COM | Through power slide switch |
| − | GND | |

> **Configuration A (3000mAh, JST 1.25mm):** Requires a JST 1.25mm → JST 2.0mm adapter cable.
> **Configuration B (2200mAh, JST 2.0mm):** Plugs directly into onboard JST connector (B2B-PH-K-S, ID 6 in BOM).

---

## 10. Decoupling & Filter Capacitors

| Designator | Value | Placement |
|---|---|---|
| C1 (qty 20 available) | 10µF 0805 | One across each VCC/GND near IC power pins |
| C2, C3 | 100nF 0603 | Across VCC/GND at LS7183N-S and joystick |
| C4 | 100µF radial | Main bulk cap on 3.3V rail |

---

## 11. Screw Terminals (U1–U4) and Expansion Header (U5)

Four **6-pin screw terminals (KEFA KF128-2.54-6P)** and one **8-pin ZX-HY2.0 connector** provide break-out points for additional modules.

| Connector | Typical Use |
|---|---|
| U1 | Encoder interface (A, B, BTN, VCC, GND, NC) |
| U2 | Joystick interface (X, Y, BTN, VCC, GND, NC) |
| U3 | Switch breakout (Cherry, Missile, spare GPIOs) |
| U4 | LED + Buzzer interface (R, G, B, BUZ, VCC, GND) |
| U5 (8-pin ZX-HY2.0) | Expansion (I2C, extra ADC, future sensors) |

---

## Summary Pinout Table

| ESP32-S3 Pin | Signal | Component |
|---|---|---|
| IO1 | JOY_X (analog) | Hall Effect Joystick X |
| IO2 | JOY_Y (analog) | Hall Effect Joystick Y |
| IO3 | JOY_BTN | Joystick click |
| IO4 | SW_CHERRY | Cherry MX Blue |
| IO5 | SW_MISSILE | Illuminated Toggle |
| IO7 | LED_R | RGB LED Red (via 220Ω) |
| IO8 | LED_G | RGB LED Green (via 220Ω) |
| IO9 | LED_B | RGB LED Blue (via 220Ω) |
| IO10 | BUZZER | Passive Buzzer (via 330Ω) |
| IO14 | ENC_BTN | Encoder push-button |
| IO15 | ENC_A (QU) | LS7183N-S CW output |
| IO16 | ENC_B (QD) | LS7183N-S CCW output |
| IO35 | OLED_MOSI | SPI Data |
| IO36 | OLED_CLK | SPI Clock |
| IO37 | OLED_CS | OLED Chip Select |
| IO38 | OLED_DC | OLED Data/Command |
| IO39 | OLED_RST | OLED Reset |
| 3.3V | VCC | All 3.3V peripherals |
| GND | GND | Common ground |

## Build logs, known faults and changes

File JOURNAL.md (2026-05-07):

# The Nerve Build Logs

_My first hardware project ever._

Approximate time: **~82h**

I found Blueprint while I was already around Flavortown. I almost didn't start anything because I thought the deadline was too close, and I was also traveling, but this idea kept coming back. I didn't want to make only another macropad. I wanted something physical for the stuff I keep doing in browser tabs: `n8n`, webhooks, video things, little automations, maybe a homelab later. _Keeping all of that only on the web is kind of boring_ :/

So The Nerve started as this idea of a **small control board** with real controls outside and an `ESP32` inside. At the start I did not know if it would work. I just knew I wanted to try.

---

### Feb 1

_Time spent: ~4h_

The first thing I thought about was the joystick. I liked the idea of using a `Hall Effect` one because I wanted smooth control and less noise/drift than a normal cheap joystick.

I was still not drawing the final PCB here. It was more like opening tabs, reading, looking at examples, thinking how this could connect with macros and webhooks. I kept thinking "ok but what would I actually use this for after building it?" because I didn't want it to be just a box with buttons.

The rough idea became: **joystick** for fine control, `OLED` for quick status, encoder for changing values, and a switch/button for actions that should feel physical.

---

### Feb 3

_Time spent: ~5h_

Started the schematic in `EasyEDA`. The first annoying thing was the `KF128` terminal. I couldn't find the exact footprint I needed, and using a random one felt like asking for problems later, so I made the footprint myself.

It sounds small, but this took more patience than I expected. Pitch, drill holes, spacing, checking if it made sense... _that kind of boring work that is only boring until it ruins the board_.

I also started organizing the power side. I added the `LDO` and tried to keep the `OLED`/main logic on a stable path. I was already worried that display/power noise could make the joystick readings worse.

Schematic

---

### Feb 7

_Time spent: ~3h_

This was where the **panic button** idea came from. I was using my sister's `ARM64` notebook, which is basic and doesn't have much memory. `Lapse` was also changing a lot because it is a Hack Club app and they are always improving stuff, so maybe some build/update broke a small part of the upload flow for me.

One upload got stuck around the middle and I lost hours of recording/proof. I was at home. It was not even a cool dramatic moment, it was just _sitting there angry because hours of work disappeared for something stupid_.

I remember thinking something like: "_man, I need an emergency save thing. I can't lose renders, automation data, proof, whatever, just because the browser decided to die._"

That's how the physical save/panic switch got into the design. Not exactly only `git commit`, because `git`/GitHub already save code well, but the idea of forcing a **snapshot/state save** for important project stuff. A real button for "please save this now before something breaks again" :)

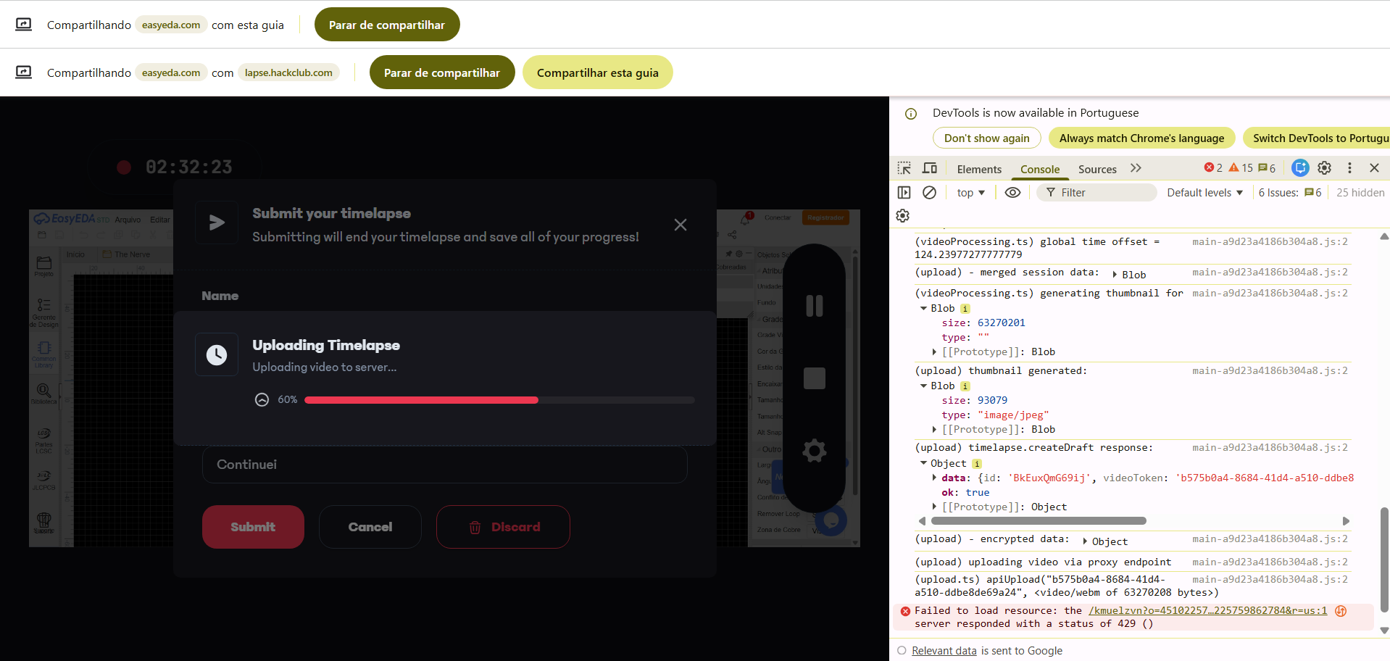
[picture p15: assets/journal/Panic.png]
Panic Button Concept


---

### Feb 11

_Time spent: ~2.5h_

I changed the `OLED` from `I2C` to `SPI`.

At first `I2C` looked simpler, but the display is supposed to show useful status while the device is being used, not just sit there. `SPI` seemed better for that because it is faster and more comfortable for screen updates.

The downside is that now I had faster digital lines on a board that also has analog joystick signals. So the display choice made the routing more annoying later. _That is the kind of thing I only started to understand while doing it._

---

### Feb 12

_Time spent: ~2h_

I decided to use the `ESP32-S3 ProS3`. A normal `ESP32` would be cheaper, but it doesn't have native `USB HID` in the way I needed. I wanted The Nerve to be able to act like a keyboard/controller for macros and debugging, and also use Wi-Fi/Bluetooth for webhooks/`n8n` stuff.

The `ProS3` having `LiPo` charging helped a lot too. I really did not want to add a separate charging circuit like a `TP4056` on my first board if I could avoid it. _There was already enough to mess up._

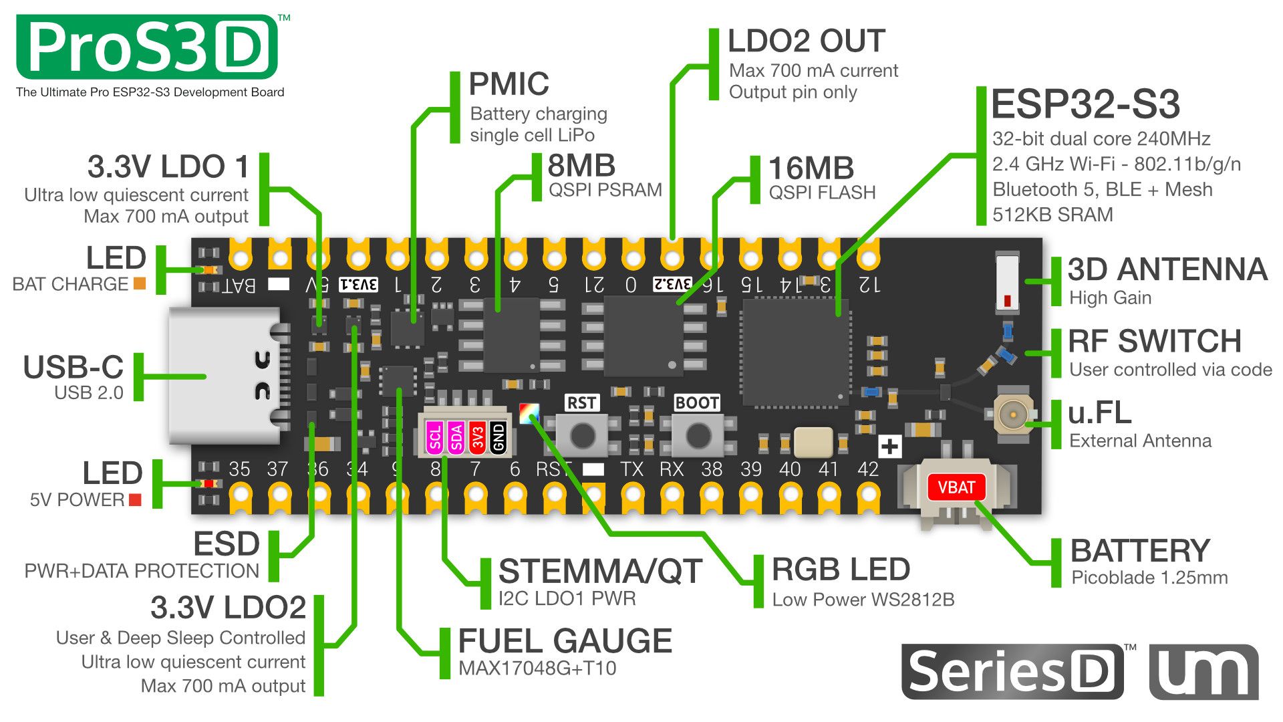
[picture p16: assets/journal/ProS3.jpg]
ESP32-S3 ProS3


---

### Feb 13

_Time spent: ~4h_

I started changing the board so the **external parts were not soldered straight into it**.

This came from how I like to build things. I like testing, touching, swapping parts, changing my mind. If the joystick starts drifting later, or if I want another encoder, or if a switch breaks, desoldering it from the PCB sounds like pain. And if I damage the board while doing that, then the whole project suffers.

So I moved more things to `JST` connectors and `KF128` terminals. It made the board feel less like one fixed object and more like a base where the parts plug in.

Later, when I removed `PCBA` to save money, this decision made even more sense. If I am already soldering the `PCB` by hand, I don't want every external part to also be a permanent problem.

---

### Feb 14

_Time spent: ~7h_

**Routing day.** A lot of routing and complaining :/

The `SPI` lines had to stay away from the analog joystick traces as much as possible. I was trying to keep them short, route them cleanly, and add **ground guard traces** between sensitive parts. I don't know if every small choice here is perfect, but I was at least trying to not make a noisy mess.

This was also when I started seeing why `PCB` work takes time. _You move one trace and suddenly three other things are worse._ Then you fix those and the board looks ugly. Then you change it again.

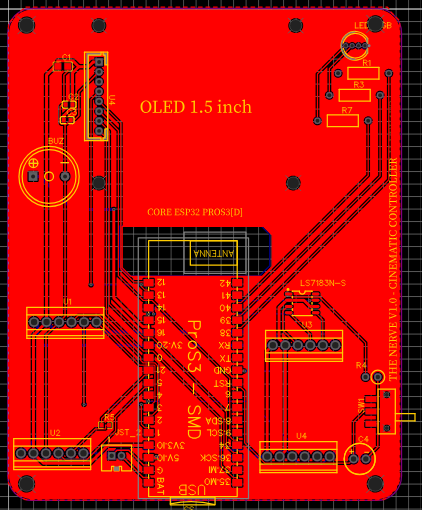
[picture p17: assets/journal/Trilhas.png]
PCB Routing


---

### Feb 15

_Time spent: ~5h_

Worked more on the second layer, vias, ground pours, and `DRC`.

Some warnings made sense quickly, some didn't. I kept looking at the board visually too because passing a check in the editor doesn't mean I will understand the board later. _I wanted future me to open the file and not hate past me too much._

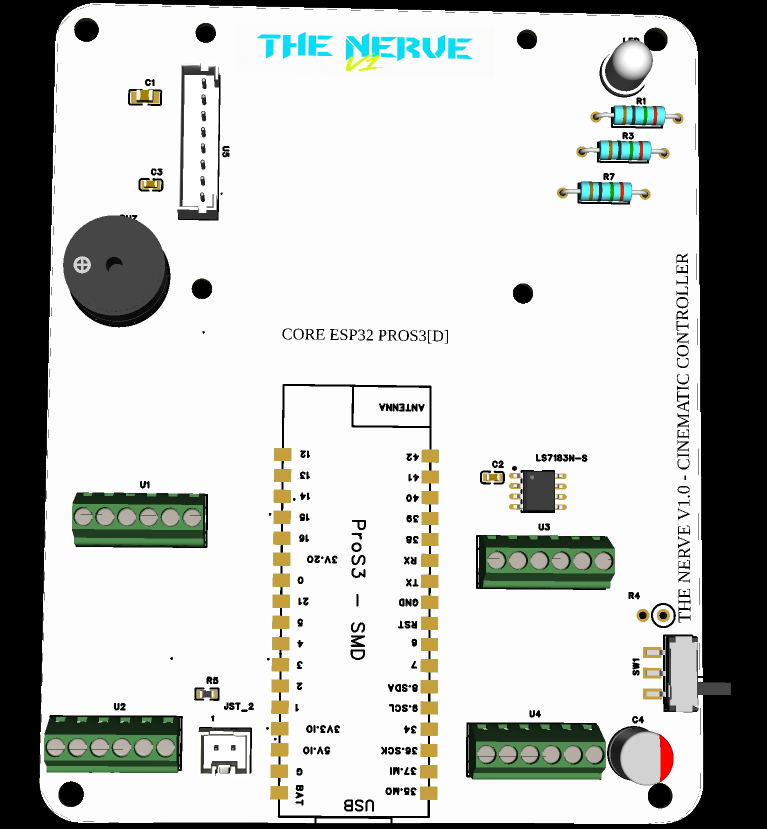
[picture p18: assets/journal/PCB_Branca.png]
Final PCB Design


---

### Feb 18 - 19

_Time spent: ~9h_

`OnShape` on Android was bad for this. I didn't remember the tool that well, and on the app the buttons/menus are different enough that I had to keep searching for basic stuff. Uploading footprints and 3D files, like the `ESP32-S3` model from Unexpected Maker, was also painful. Internet would get bad, upload would fail, and after some time I just gave up on the app because _I was more likely to break the design than improve it_.

Around Feb 10, I think, my own **Positivo notebook** arrived. That helped a lot. It is not a gaming PC, but I am not playing much now anyway, and for `EasyEDA`/docs/tabs it was enough. A 15.6" screen after trying to do things in worse setups felt very good :D

The weird network thing happened on my notebook, not my sister's. `OnShape`'s `/en` URL didn't load right. I had seen something kind of similar with GitHub Codespaces before, where I thought maybe I was blocked because of compute hours, but I looked at the usage page and it wasn't that. I opened `F12`, looked at the network stuff, and thought: "_what if I route this like it is coming from the US?_" Tried a VPN and it loaded.

It didn't take forever to solve, but _these small blocks eat patience_.

---

### Feb 20

_Time spent: ~5h_

I worked more on the enclosure using the `EasyEDA` `STEP` in `OnShape`. I wanted the case tilted because a flat box on the desk would be worse to look at and use, so I made it around **15 degrees**.

I also added back ventilation. The `ESP32-S3` can get warm if it is doing more things, and closing everything inside a printed case with no airflow felt wrong. Maybe the vents are not magic, but at least _I am not pretending heat doesn't exist_.

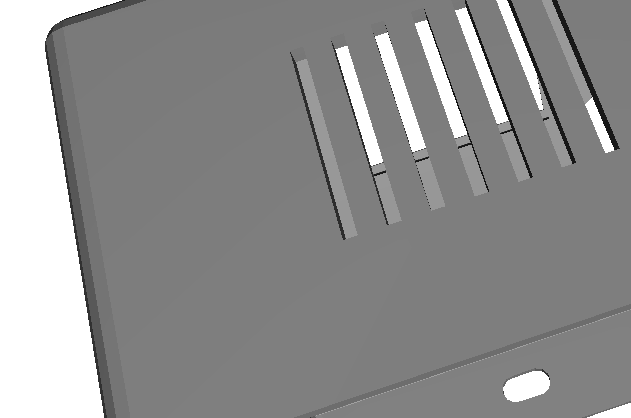
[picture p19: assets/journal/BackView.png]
Back Ventilation Slots


---

### Feb 27

_Time spent: ~8h_

I worked on the firmware logic without having the physical parts. _This is weird because you are kind of writing for hardware that exists only in your head and files._

I renamed the firmware to `main.py`, cleaned some ideas, and thought about how the joystick/encoder/`OLED`/panic button would map to real actions. `n8n` webhooks, `HID` macros, status on screen, things like that.

Some of it was not final code, more like testing the logic and seeing if the hardware choices still made sense. **I wanted each part to have a reason to exist.**

---

### Feb 28 - Mar 10

_Time spent: ~7.5h_

_This part is hard to write as one clean story because it was not clean._ It was small work spread across days.

I adjusted routes, fixed little `CAD` things, organized files, lost/missed some `Lapse` recordings, and kept checking if the external parts made sense with the `PCB`. A reviewer had mentioned that I had cart items that were not clearly shown in the design, so I tried to make that connection more obvious.

_This is the kind of project work that doesn't look impressive in one screenshot but still takes hours._

---

### Mar 12

_Time spent: ~4h_

**Budget time.** Not fun, but necessary.

I saw that some parts were much cheaper on AliExpress than on Mouser, especially things like the joystick and encoder. So I changed sources in the `BOM` and recalculated.

This was when the project started turning into "_can I actually fit this under the grant limit?_" instead of only "_can I design this?_"

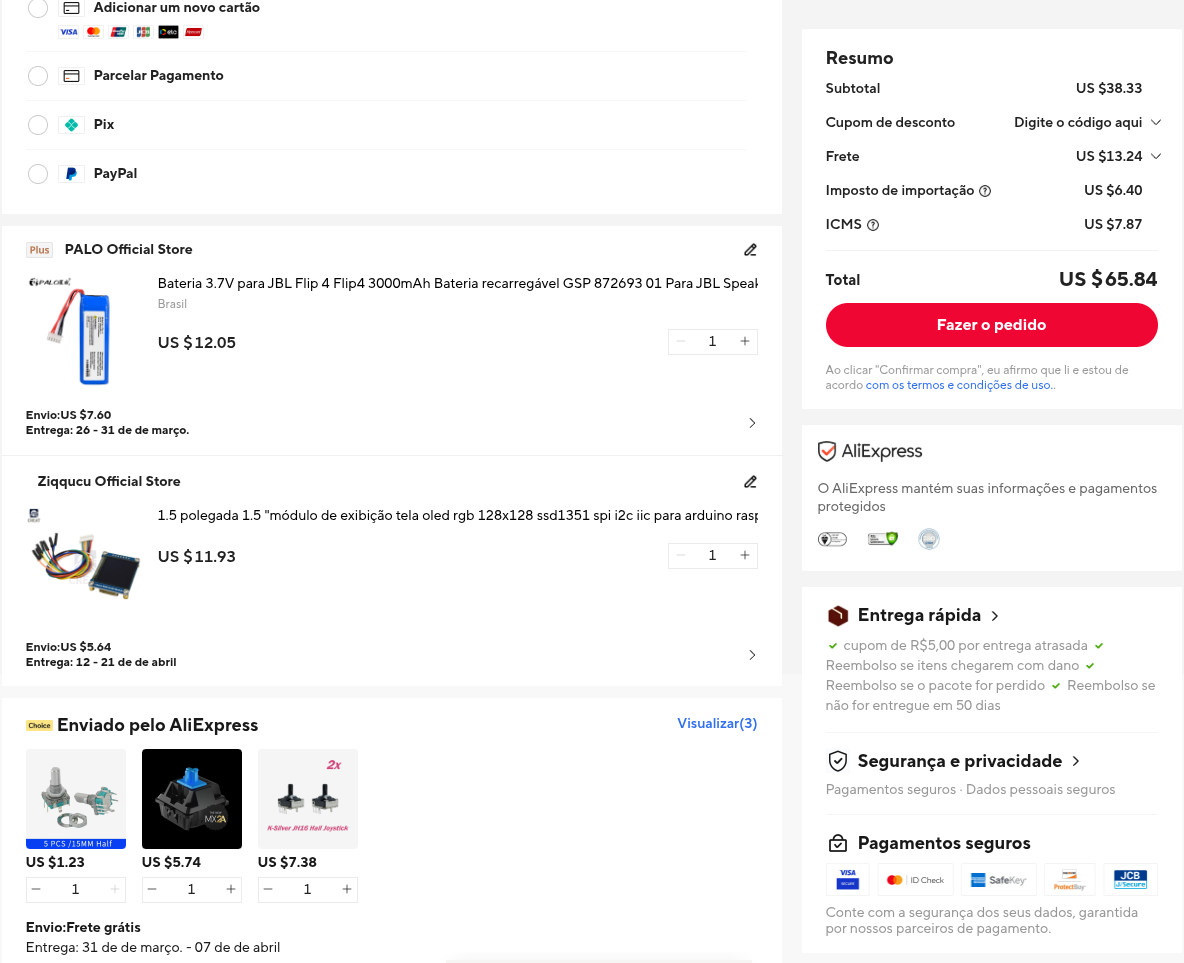
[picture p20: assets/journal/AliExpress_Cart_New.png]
AliExpress Cart


---

### Mar 22

_Time spent: ~3h_

Reviewer feedback asked why the battery was needed and why `ESP32-S3` instead of something cheaper.

Fair questions. The battery is there because standalone mode is part of the point. If The Nerve always needs a PC/USB cable for power, then it loses a lot of the webhook/automation idea. And the `ESP32-S3` is because of native `USB HID` plus Wi-Fi/Bluetooth, and the `ProS3` also saves me from adding a separate charger circuit.

I rewrote those explanations so the reviewer would not have to guess.

---

### Mar 24

_Time spent: ~3h_

I simplified some things, changed cheaper `BOM` parts, and added the `JLCPCB` shipping verification that had been requested.

Here I started learning that **hardware documentation is almost another project**. It is not enough to have files. The reviewer needs to see prices, carts, why the parts exist, and how everything connects.

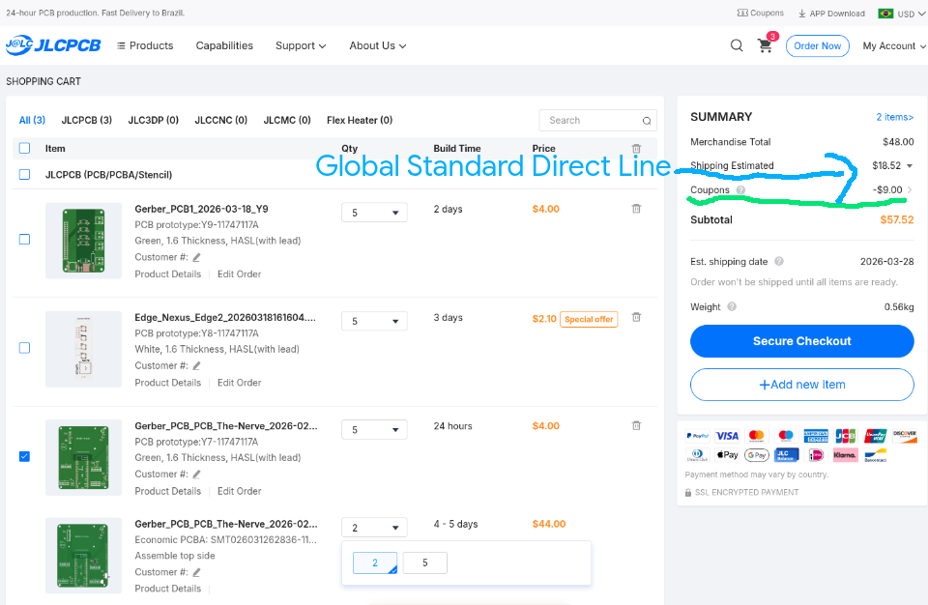
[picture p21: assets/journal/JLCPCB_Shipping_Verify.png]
JLCPCB Shipping Verification


---

### Mar 25

_Time spent: ~2h_

I tried to do a final verification. _It didn't really feel final_ :(

I looked at the submission form, files, screenshots, and repo organization. Some things were okay, some things still felt like they might need another pass. This happened a lot with this project. I would think "ok now it is done" and then one more image/price/explanation would be wrong or missing.

---

### April 15

_Time spent: ~4h_

I reorganized docs and kept looking for a battery. I needed one that would fit the enclosure and ideally already have `JST` with `2mm pitch`. That sounds simple until you actually start checking sizes, connectors, and availability.

I also removed `PCBA` from `JLCPCB` because it was over $40 and pushed the project too close/outside the Tier 3 budget. That means hand soldering, including small `0603` parts. _Not exactly relaxing._

But it also made the connector/modularity choice feel right. If something goes wrong with an external part, I don't want to desolder half the project.

---

### April 28

_Time spent: ~0h project work_

Not much progress. _Real life got in the way._

The dollar was around the normal painful value here, close to `R$5` for `$1`, and I saw people talking about Hack Club maybe not covering shipping/taxes. That made me worry a lot because hardware in Brazil gets expensive fast. I even wondered if there was some kind of document that could help show it is a STEM/student donation thing, but I don't know.

Also college started taking space in my brain: Calculus, Analytical Geometry, programming things, house stuff. For a while I thought the review window had already passed, so I kind of left the project aside.

_Not a productive log, but it is true_ :/

---

### May 5

_Time spent: ~4h_

I saw that re-review still seemed open, so I did another final pass. Again "_final_" lol.

I took/added new cart screenshots, looked at the prices again, fixed the `BOM`/budget numbers, and made sure the `BOM` was using only merchandise/component prices, not shipping and taxes.

- Adafruit: $30.45
- JLCPCB: $4.00
- AliExpress: $40.92
- LCSC: $14.18
- **Final hardware cost:** $89.79

I also fixed the `PCB` image label because the blue layer was **bottom**, not top. That one was important because calling a PCB layer wrong looks bad. Then I restored the colorful `Tinkercad` render because the grey render was too lifeless and didn't show the project well. The colorful one shows the joystick, `OLED`, encoder, and switch sitting on the enclosure, which is much clearer.

Final PCB Bottom Layout
Enclosure Hero Render
Enclosure Back View
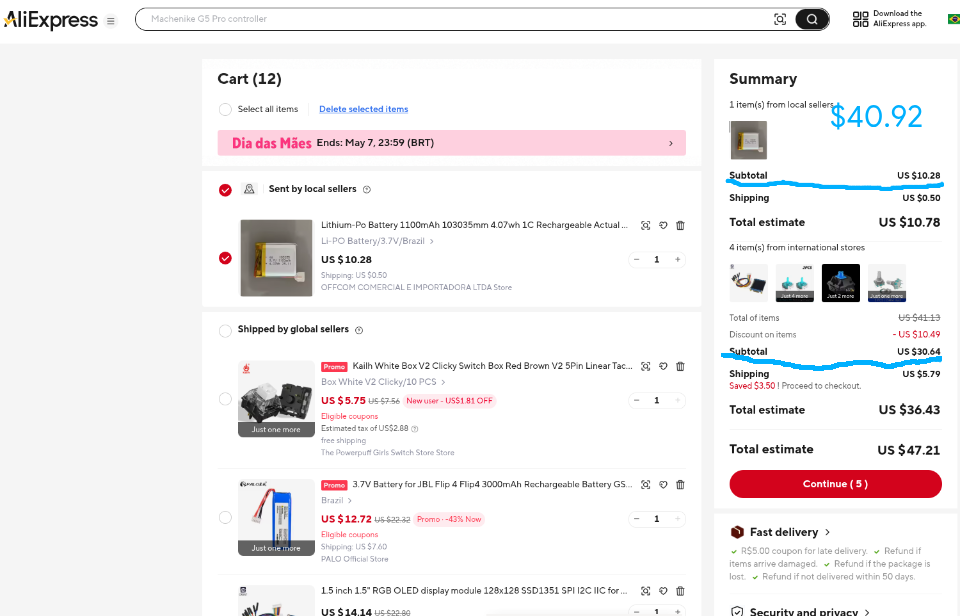
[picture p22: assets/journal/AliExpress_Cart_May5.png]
Final AliExpress Cart


Now I think it is ready for re-review. I hope :D

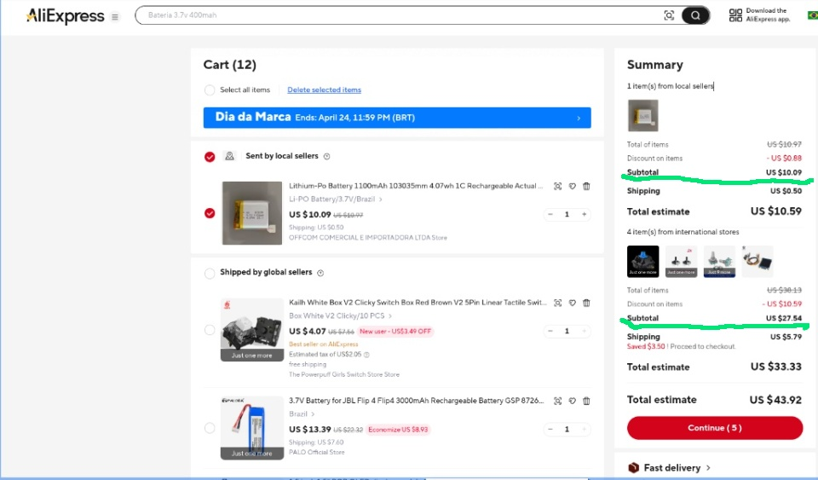
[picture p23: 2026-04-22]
assets/journal/AliExpress_Cart_Final.png

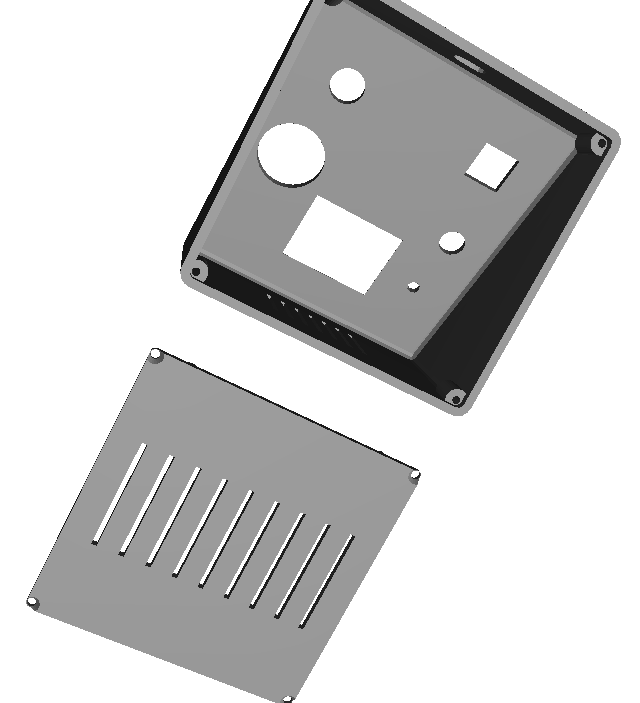
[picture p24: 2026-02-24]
assets/journal/ViewBottom.png

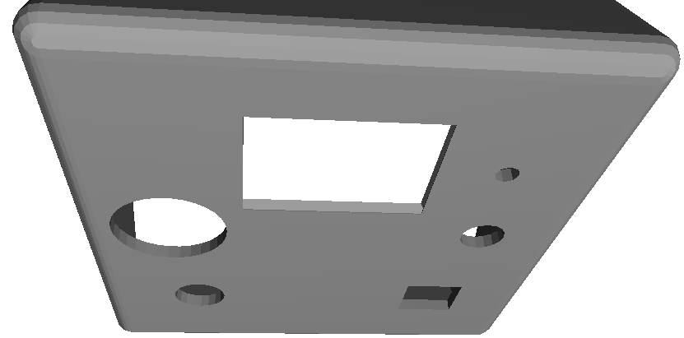
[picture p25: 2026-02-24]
assets/journal/Chanfro.png

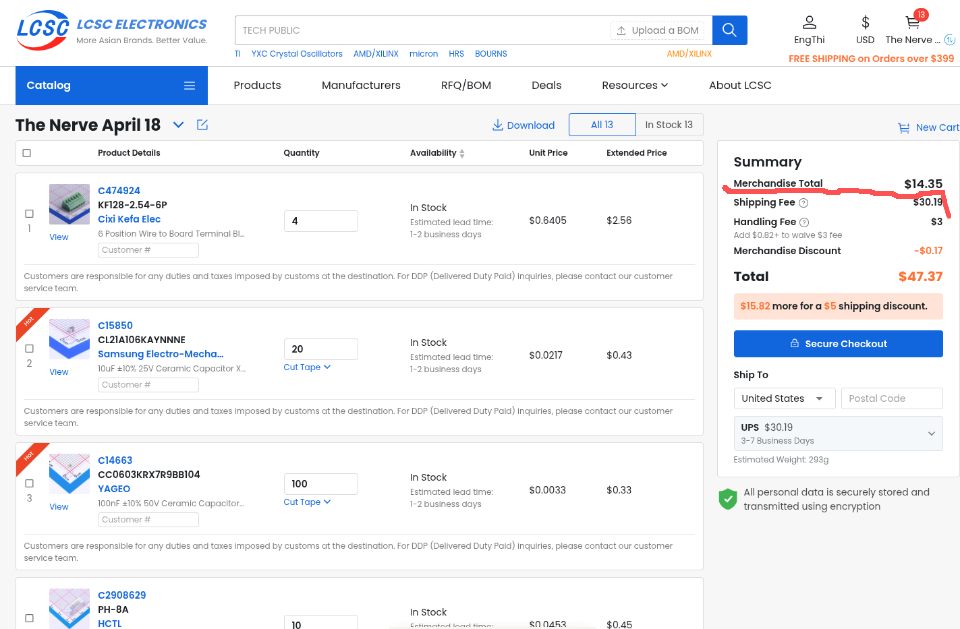
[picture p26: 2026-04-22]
assets/journal/LCSC_Cart_Shipping.png

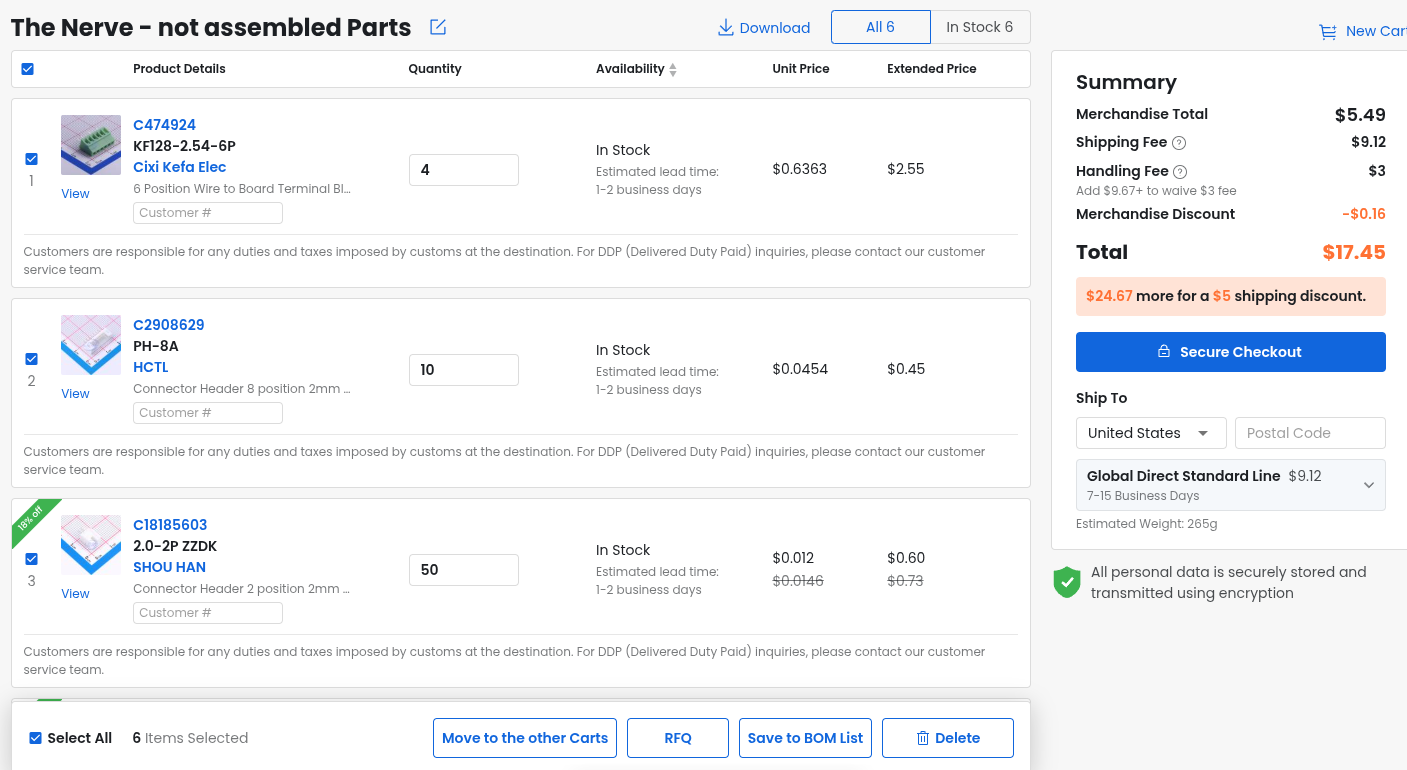
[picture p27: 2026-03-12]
assets/journal/LCSC_Cart.png

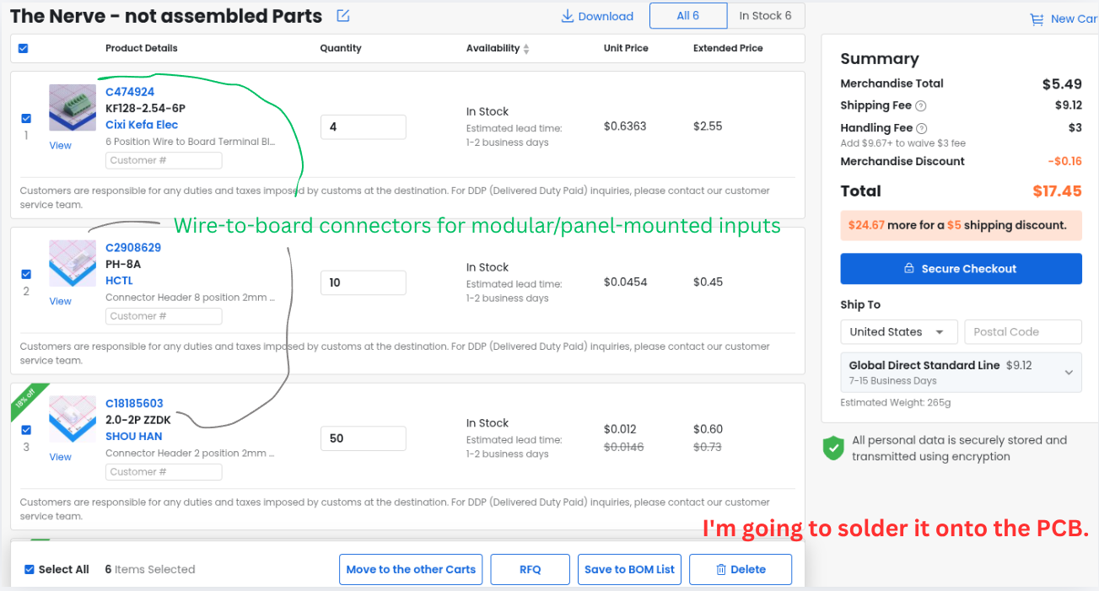
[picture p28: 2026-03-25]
assets/journal/LCSC_Cart_Updated.png

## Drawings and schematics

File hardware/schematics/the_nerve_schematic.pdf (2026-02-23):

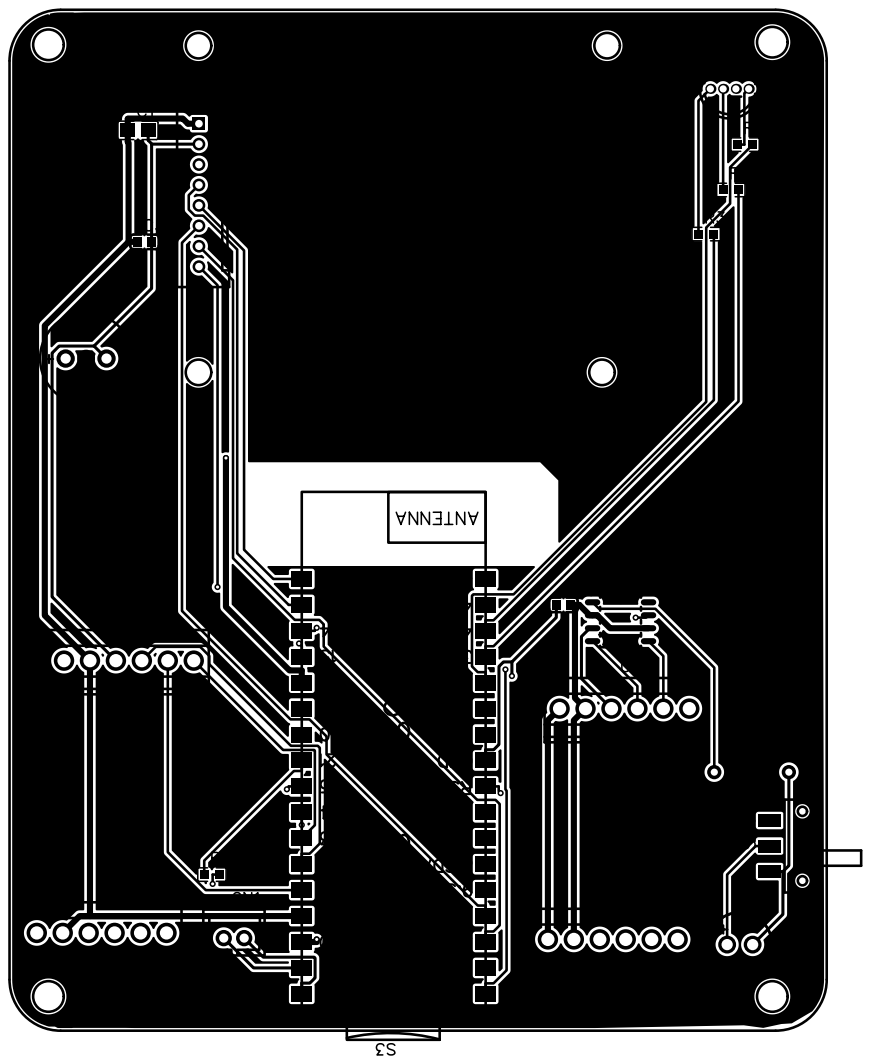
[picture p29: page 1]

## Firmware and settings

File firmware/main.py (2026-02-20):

import machine
import time
import json
from machine import Pin, ADC, PWM

# --- CONFIGURAÇÃO DE PINAGEM (MAPA OFICIAL PROS3) ---

# 1. Joystick (ADC1 - WiFi Safe)
# No ESP32-S3, os ADC1 são os pinos 1 a 10. O range é 12-bits (0 a 4095).
joy_x = ADC(Pin(1))
joy_y = ADC(Pin(2))
joy_sw = Pin(3, Pin.IN, Pin.PULL_UP)

# Atenuação de 11DB permite ler até ~3.1V (Perfeito para Joystick de 3.3V)
joy_x.atten(ADC.ATTN_11DB)
joy_y.atten(ADC.ATTN_11DB)

# 2. Encoder Óptico via LS7183N-S (Pulsos de Hardware)
# O chip LS7 entrega pulsos de UP e DOWN limpos. Não precisamos de debounce de hardware aqui.
enc_up = Pin(15, Pin.IN, Pin.PULL_UP)
enc_dn = Pin(16, Pin.IN, Pin.PULL_UP)
enc_sw = Pin(14, Pin.IN, Pin.PULL_UP)

# 3. Gatilhos Modulares JST
mx_switch = Pin(4, Pin.IN, Pin.PULL_UP)     # Execute (Cherry MX)
missile_sw = Pin(5, Pin.IN, Pin.PULL_UP)    # Safety Toggle
missile_led = Pin(21, Pin.OUT)              # LED da capa do switch

# 4. Feedbacks On-Board (PWM)
# No MicroPython do ESP32, o duty_u16 vai de 0 a 65535 (16 bits)
buzzer = PWM(Pin(18), freq=1000, duty_u16=0)
led_r = PWM(Pin(38), freq=5000, duty_u16=0)
led_g = PWM(Pin(39), freq=5000, duty_u16=0)
led_b = PWM(Pin(40), freq=5000, duty_u16=0)

# --- ESTADO DO SISTEMA ---
hype_level = 50
system_armed = False

def set_led(r, g, b):
    """
    Define a cor do LED RGB.
    Recebe (r,g,b) de 0 a 255 e converte para duty_u16 (0-65535).
    Se o seu LED for Cátodo Comum, maior valor = mais luz.
    Se for Ânodo Comum (como na maioria das devboards), inverta a lógica.
    """
    # Ex: r=255 -> 255 * 257 = 65535
    led_r.duty_u16(int(r * 257))
    led_g.duty_u16(int(g * 257)) 
    led_b.duty_u16(int(b * 257))

def play_alert(freq, duration):
    """Toca um tom no buzzer usando duty_u16 (50% = 32768)"""
    buzzer.freq(freq)
    buzzer.duty_u16(32768) # 50% de duty cycle (volume máximo)
    time.sleep(duration)
    buzzer.duty_u16(0)     # Desliga

# --- LÓGICA DO ENCODER LS7183N (PULSOS) ---
last_up = enc_up.value()
last_dn = enc_dn.value()

print("🎬 THE NERVE V1.0 - PROS3 EDITION ONLINE")
play_alert(2000, 0.2)
set_led(0, 50, 200) # Inicia Azul Cyperpack

while True:
    # 1. Gerenciamento de Segurança (Missile Switch)
    # Supondo que ligado (capa pra cima) feche para GND (0)
    system_armed = not missile_sw.value()
    missile_led.value(1 if system_armed else 0) # Acende LED do Missile se armado

    # 2. Hype Dial (Lógica para o chip LS7183N)
    curr_up = enc_up.value()
    curr_dn = enc_dn.value()
    
    # Detecta a borda de descida (quando o pino vai de 1 para 0)
    if curr_up == 0 and last_up == 1: 
        hype_level = min(100, hype_level + 5)
        # Gradient: 0 = Azul (0,0,255), 100 = Vermelho (255,0,0)
        set_led(int((hype_level/100)*255), 0, int(((100-hype_level)/100)*255)) 
    elif curr_dn == 0 and last_dn == 1: 
        hype_level = max(0, hype_level - 5)
        set_led(int((hype_level/100)*255), 0, int(((100-hype_level)/100)*255))
        
    last_up, last_dn = curr_up, curr_dn

    # 3. Timeline Scrubbing (Joystick)
    # ESP32-S3 ADC retorna 0 a 4095 (12 bits). Centro é ~2048.
    # Lemos read_u16 para ter mais precisão (0-65535) mas read() simples basta.
    # Normalizando ADC (0-4095) para Range de -100 a +100
    try:
        raw_x = joy_x.read()
        raw_y = joy_y.read()
        x_val = int((raw_x - 2048) / 20.48)
        y_val = int((raw_y - 2048) / 20.48)
        
        # Deadzone (ignora movimentos pequenos do dedo)
        if abs(x_val) < 10: x_val = 0
        if abs(y_val) < 10: y_val = 0
    except Exception as e:
        x_val, y_val = 0, 0

    # 4. Gatilho Final (Absolute Cinema Execution - Cherry MX)
    if not mx_switch.value():
        if system_armed:
            msg = {
                "event": "RENDER_NOW",
                "params": {
                    "hype": hype_level,
                    "scrub_x": x_val,
                    "scrub_y": y_val
                },
                "meta": "SHIP_IT"
            }
            print(json.dumps(msg)) # Envia para o n8n via Serial
            set_led(255, 255, 255) # Flash Branco (Cinema effect)
            play_alert(1500, 0.3)
            time.sleep(1) # Impede duplo clique acidental
        else:
            # Alerta de Segurança: Tentativa sem armar
            print(json.dumps({"warning": "SAFETY_LOCK_ACTIVE"}))
            set_led(255, 0, 0)
            play_alert(400, 0.1)
            time.sleep(0.5)

    time.sleep(0.01) # Loop a 100Hz para capturar o encoder rápido

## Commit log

2026-02-14 Organizaçao de tudo no repo além de terminar o README que já vinha pensando
    [BOM.csv, BOM_The-Nerve_2026-02-13.csv, PickAndPlace_PCB_The-Nerve_2026-02-13.csv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]
2026-02-15 Deletei o case_v1.step
    [case_v1.step]
2026-02-19 feat(project): Documentação, BOM e Organização Geral do Projeto
    Atualiza e finaliza a Lista de Materiais (BOM), movendo-a para a raiz do projeto como 'BOM.csv'.
    A BOM agora inclui todos os componentes, com preços e links corrigidos, e apresenta duas opções de bateria com notas explicativas sobre a compatibilidade dos conectores.
    Melhora a documentação principal (README.md) com a adição de imagens do projeto, incluindo o render da PCB, o logo e uma prévia da fabricação.
    Reorganiza a estrutura de arquivos para alinhar com as melhores práticas.
    CORREÇÃO: Adiciona o README.md que foi modificado, mas esquecido no commit anterior.
    [BOM.csv, BOM_The-Nerve_2026-02-13.csv, PickAndPlace_PCB_The-Nerve_2026-02-13.csv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]
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2026-02-20 feat(bom): Adiciona opções de encoders mecânico e óptico
    Adiciona o encoder mecânico Alps (EC11E15244B2) e o encoder óptico de alta precisão Bourns (ENA1J-B28-L00064L) à Lista de Materiais.
    Corrige a formatação geral do CSV e padroniza links de fornecedores para melhor legibilidade.
    [BOM.csv]
2026-02-20 docs: Atualiza custos totais e corrige quantidades na BOM
    Refaz o cálculo total de custo considerando todos os itens e opções da BOM (60.70).
    Corrige a quantidade do switch Cherry MX Blue para 1 unidade.
    Garante que a documentação reflita a estrutura completa de custos.
    [BOM.csv]
2026-02-20 Ajustes no firmware e arquivos do sistema
    - Adiciona mudanças no firmware.py esquecidas anteriormente.
    - Pequena correção no arquivo de configuração do IDX.
2026-02-21 Adiciona modelos 3D da case
    - Inclui os arquivos STL para o corpo principal, tampa e montagem completa.
    - Organiza os modelos na pasta hardware/3d_models/ com nomes padronizados.
    [the_nerve_case_bottom.stl, the_nerve_case_full_assembly.stl, the_nerve_case_main.stl]
2026-02-22 Adiciona renders da case do projeto
    - Inclui imagens da visão inferior, da case principal e juntas da case.
    - Organiza as imagens na pasta de assets com nomes descritivos.
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2026-02-22 docs: Add mechanical hardware (wires, screws, inserts) to BOM
    [BOM.csv]
2026-02-22 docs: Update wire kit to specific BNTECHGO 10-color set and remove unnecessary mechanical items
    [BOM.csv]
2026-02-22 docs: Update JOURNAL replacing OpenSCAD with OnShape and add full CAD specifications
2026-02-22 docs: Update project total cost and add silicone wiring kit to BOM table
2026-02-22 docs: Update BOM with actual LCSC buzzer and RGB LED pack quantities and prices
    [BOM.csv]
2026-02-22 docs: Update README with new buzzer and RGB LED pack costs, total to $171.92
2026-02-23 docs: Update 10uF Capacitor to correct LCSC part C1713 with Cut Tape min qty 20
    [BOM.csv]
2026-02-23 docs: Add secondary BOM exclusively for JLCPCB assembly (PCBA) with correct 16-column format and updated C1713 capacitor
    [BOM_JLCPCB_PCBA.csv]
2026-02-23 Update hardware design files to v2026-02-23
    - Updates Gerbers, Pick and Place, and Schematic PDF to the latest versions.
    - Updates the PCB project JSON and adds the new OBJ 3D model.
    - Maintains the custom BOM.csv with updated prices and external modules.
    [the_nerve_pick_and_place.csv]
2026-02-23 Fix URLs for encoders in BOM.csv
    Updated URLs for Mechanical and Optical Encoders in BOM.
    [BOM.csv]
2026-02-23 Correct quotes in BOM.csv
    [BOM.csv]
2026-02-23 Update JOURNAL.md with development progress and changes
    Documented the development progress, engineering decisions, and challenges faced during the development of The Nerve V1. Included updates on hardware changes, enclosure design, and BOM corrections.
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2026-03-10 feat: add firmware/src/main.py and flashing guide (resolves empty src/ complaint)
    [main.py]
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2026-03-10 feat: add hardware/pcb/the_nerve.kicad_pro (resolves missing KiCad project file)
2026-03-10 Docs: Address review feedback
    - Removes legacy Rust firmware; MicroPython is now the standard.
    - Updates README to clarify firmware and CAD file status.
2026-03-11 docs: update cost table with real checkout prices by vendor (incl. shipping, PCBA, MOQ)
2026-03-11 Feat: Add new PCB design files from EasyEDA
    - Replaces the old KiCad project with the new EasyEDA project source (.json).
    - Adds the corresponding Gerber, BOM, and Pick & Place fabrication files for the new board revision.
    - Updates the README.md to reflect the change in design software (from KiCad to EasyEDA) and the new file structure.
    [BOM_JLCPCB_PCBA.csv, the_nerve.brd, the_nerve.dxf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]
2026-03-12 Fix: Replace hardware files with the correct version
    - Replaces all PCB and fabrication files with the correct, newly uploaded versions from EasyEDA.
    - Adds the STEP model of the PCB to the '3d_models' directory.
    [the_nerve_bom.csv, the_nerve_pcb.step, the_nerve_pickandplace.csv]
2026-03-12 docs: Finalize Hack Club Blueprint budget and sanitize repository structure
    - Generated official BLUEPRINT_BUDGET.md with validated, veracious checkout amounts.
    - Updated main BOMs to accurately reflect Minimum Order Quantities (MOQ) and shipping/handling fees.
    - Separated BOMs into LCSC and External sub-lists in hardware/fabrication/ to streamline parts sourcing.
    - Cleaned up root directory: Moved proof-of-purchase screenshots to assets/journal and renders to assets/renders.
    - Deleted redundant, unformatted EasyEDA export dumps.
    - Added 'Minimum Cost to Replicate' section to the main README.
    [BOM.csv, BOM_EXTERNAL_ONLY.csv, BOM_LCSC_ONLY.csv]
2026-03-12 docs: clarify mandatory components and modular architecture for Hack Club review
    - Removed 'Optional' tags from batteries and encoders; both are mandatory for prototyping weight distribution and tactile feedback.
    - Explicitly documented the Motherboard/hand-wired approach in the README and Budget to explain why external parts are in the cart but not surface-mounted on the PCB render.
    [BOM_EXTERNAL_ONLY.csv, the_nerve_bom.csv]
2026-03-12 docs: finalize assertive budget and modular design clarification for reviewer
    - Removed all 'optional' terminology from the project.
    - Updated BLUEPRINT_BUDGET.md to 17.84 (including MOQs and mandatory parts).
    - Clarified 'Motherboard Architecture' in README to explain external component mounting.
    - Verified enclosure design references in JOURNAL.md.
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2026-03-19 docs: move and update official BOM to root with AliExpress links
    [the_nerve_bom.csv]
2026-03-19 docs: simplify BOM and move regional tax/freight notes to README
    [the_nerve_bom.csv]
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2026-03-24 docs: finalize Tier 3 optimization with cheaper encoder, wiring diagram, and standalone justification
    [the_nerve_bom.csv]
2026-03-25 docs: finalize tier 3 budget and sync BOM with new shopping cart evidence
    [the_nerve_bom.csv]
2026-03-30 docs: upgrade repository to professional standards (production folder and technical spec layout)
    [the_nerve_pickandplace.csv]
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2026-04-13 docs: strictly optimize budget to ~8 by removing PCBA and using manual SMT assembly
    [the_nerve_bom.csv]
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2026-04-22 Update budget with final component prices and add receipt screenshots
    [the_nerve_bom.csv]
2026-05-06 docs: final budget alignment and May 5th update
    [the_nerve_bom.csv]
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2026-06-06 docs: finalize the nerve version C and sync edge-nexus submodule
    [The_Nerve_LCSC_BOM_Detailed.csv, the_nerve_bom.csv]
2026-06-06 docs: sync latest manufacturing files and update OnShape link
    [the_nerve_pickandplace.csv]
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2026-06-06 docs: adjust budget and designate Version A for Tier 3 compliance
    [the_nerve_bom.csv]
2026-06-06 docs: Refactor budget to separate base parts from shipping, add usage instructions, add Tinkercad link, and update fabrication files
    [the_nerve_pickandplace.csv]
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2026-06-06 docs: Fix Shopee links and Outemu switch quantity in BOM
    [the_nerve_bom.csv]
2026-06-06 fix: Resolve illegal CSV quoting on lines 13 and 14
    [the_nerve_bom.csv]
2026-06-06 fix: Remove comment lines to fix CSV column structure
    [the_nerve_bom.csv]
2026-06-06 fix: Wrap notes column in quotes on line 12 to prevent extra CSV columns
    [the_nerve_bom.csv]
2026-06-06 docs: Finalize unified master BOM with all external components, links, and technical specs
    [the_nerve_bom.csv]
2026-06-07 fix: csv commas
    [the_nerve_bom.csv]

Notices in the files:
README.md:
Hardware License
